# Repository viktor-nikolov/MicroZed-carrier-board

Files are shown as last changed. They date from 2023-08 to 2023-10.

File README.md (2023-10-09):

# MicroZed development carrier board



This repository provides KiCad design and production files for a [MicroZed](https://www.avnet.com/wps/portal/us/products/avnet-boards/avnet-board-families/microzed/) development carrier board (a.k.a. MicroZed carrier card).

### Please see [the repository's Wiki](https://github.com/viktor-nikolov/MicroZed-carrier-board/wiki) for details.

You are welcome to leave feedback in [the discussion](https://github.com/viktor-nikolov/MicroZed-carrier-board/discussions).

#### List of features:

- 106 digital I/O pins exposed via female headers
  
  - 16 I/O pins work on 5 V (exposed via two PMOD headers), and the rest of the pins work on 3.3 V

- 2 dedicated analog input pins XADC VP/VN

- 2 LEDs

- 2 push buttons

- 50 MHz precision oscillator (intended as an external clock input to the FPGA Programmable Logic)

- UART to USB conversion chip with the micro-USB connector (intended to enable UART communication for the FPGA Programmable Logic)

- Power input via micro-USB connector or screw terminal. On board power switch.

- Compatible with both [MicroZed 7010](https://www.avnet.com/shop/us/products/avnet-engineering-services/aes-z7mb-7z010-som-g-rev-h-3074457345644698173/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) and [MicroZed 7020](https://www.avnet.com/shop/us/products/avnet-engineering-services/aes-z7mb-7z020-som-g-rev-h-3074457345644698177/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).

&nbsp;

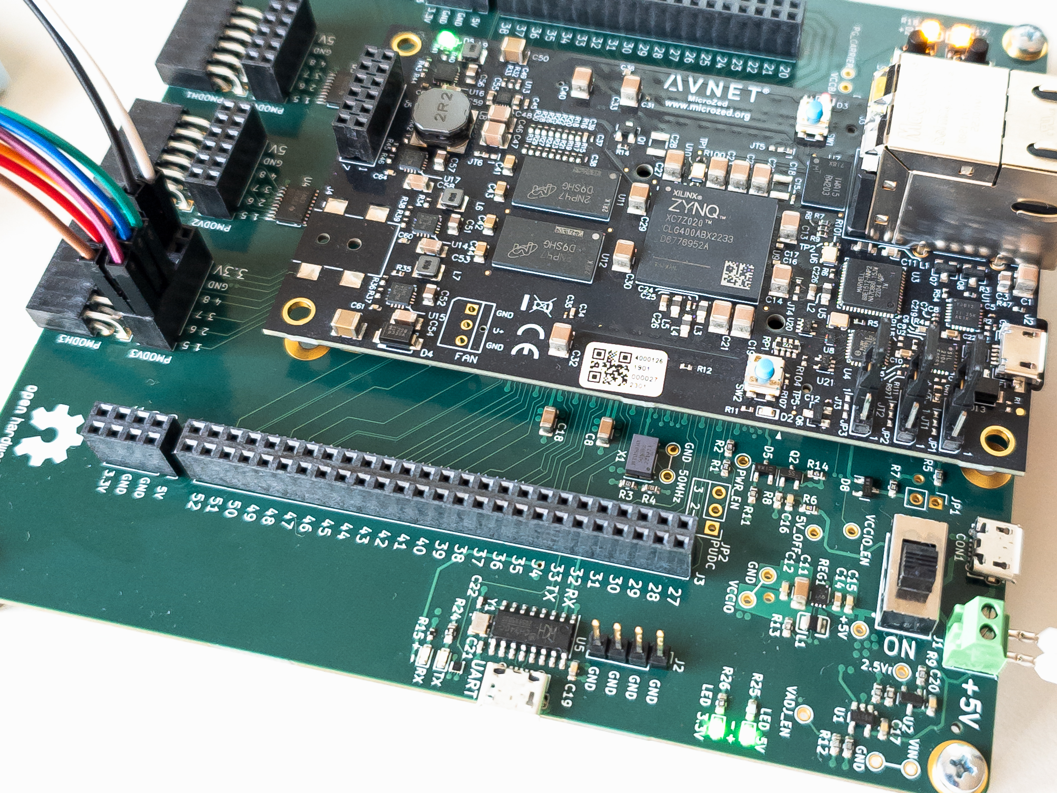
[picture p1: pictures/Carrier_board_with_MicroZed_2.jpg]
Carrier board with MicroZed
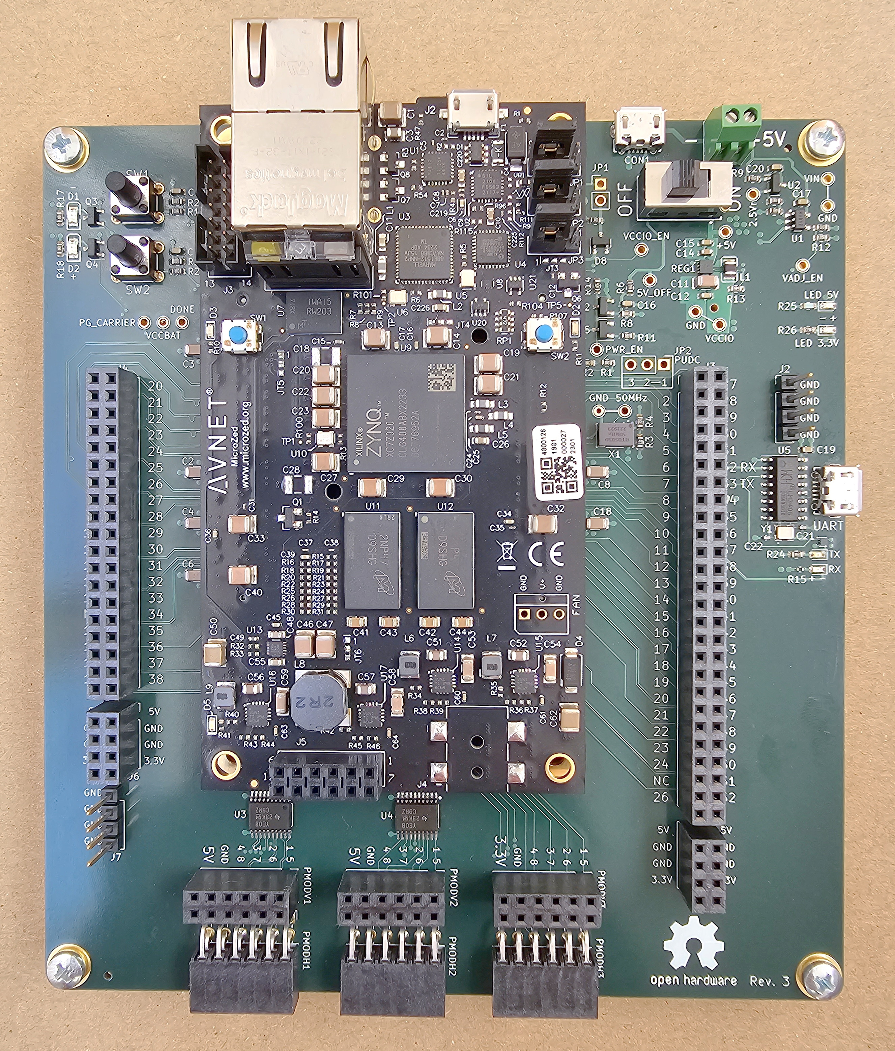
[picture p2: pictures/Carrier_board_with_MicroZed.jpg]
Carrier board with MicroZed
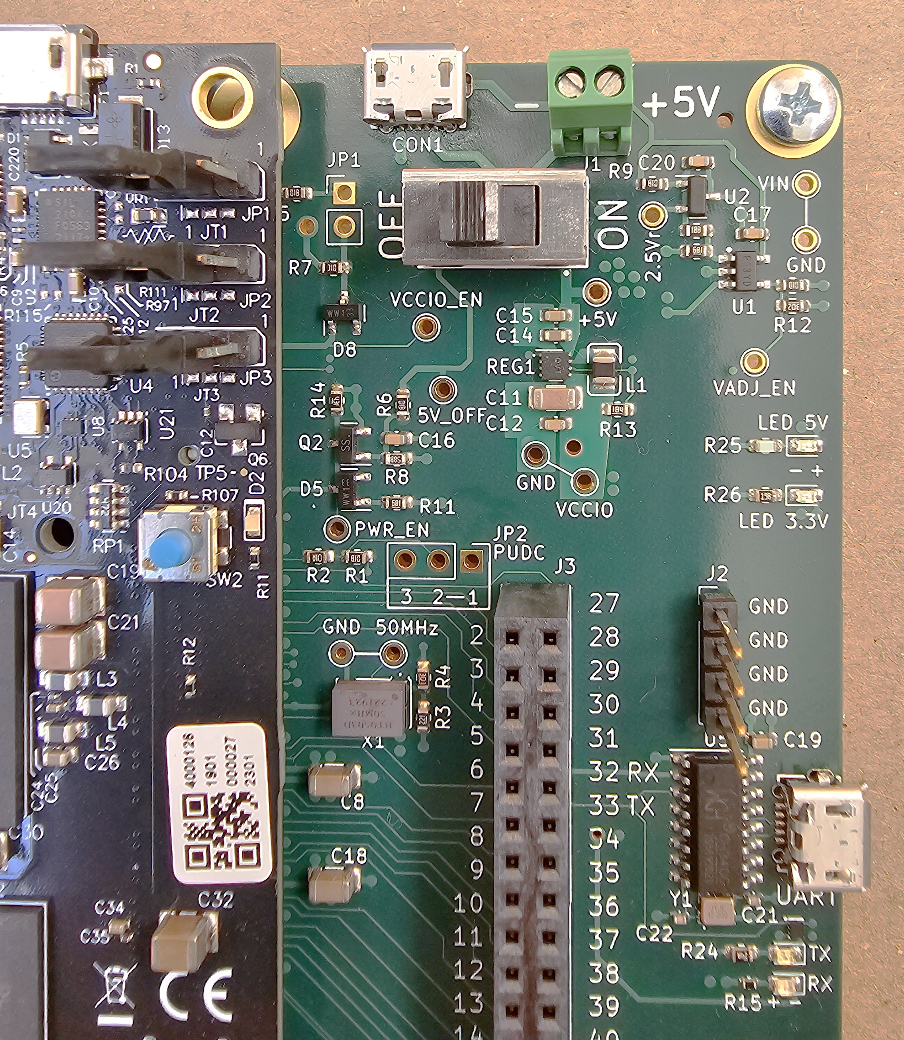
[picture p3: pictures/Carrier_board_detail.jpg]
Carrier board detail
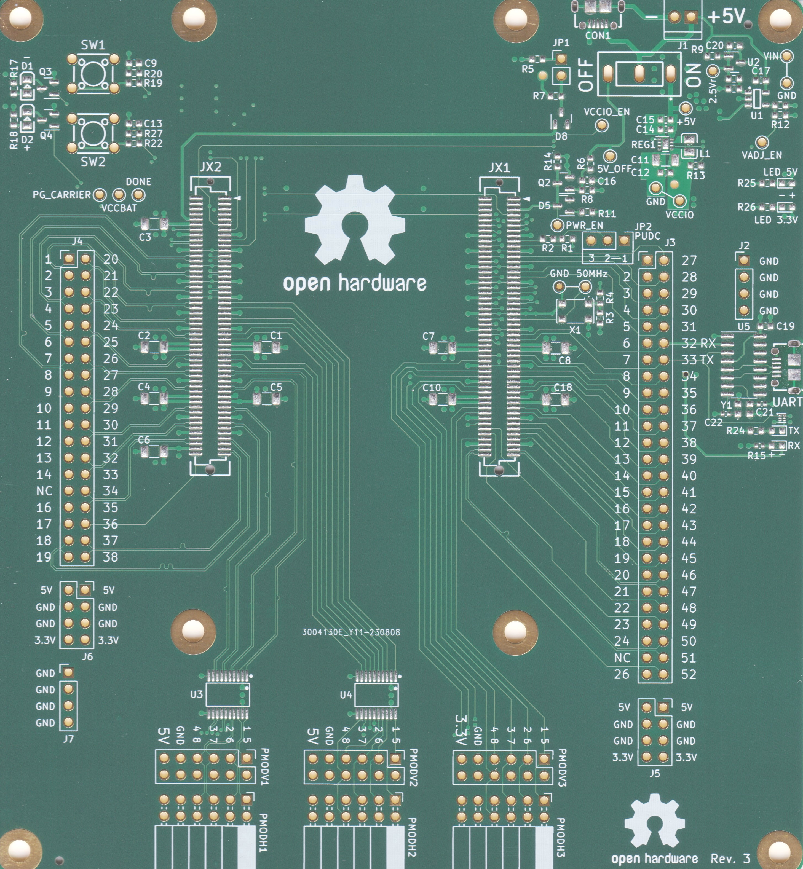
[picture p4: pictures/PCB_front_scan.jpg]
PCB front scan
            

See other photos [here](pictures).

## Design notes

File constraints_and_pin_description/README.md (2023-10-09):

### Please see [the repository's Wiki](https://github.com/viktor-nikolov/MicroZed-carrier-board/wiki#pinout) for details.

# Constraints files and pin description

- MicroZed carrier JX pinout tables &ndash; description of MicroZed JX1 and JX2 mezzanine connectors pins and their mapping to the J3, J4 and PMOD connectors on the carrier board.

- MicroZed_carrier_board_constraints_master.xdc – a general .xdc for the carrier board.
  
  - To use it in a Vivado project, uncomment the lines corresponding to used pins and, if needed, rename the used ports according to the top-level signal names in the project.

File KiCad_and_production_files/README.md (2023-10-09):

# KiCad design files and production files

### Please see [the repository's Wiki](https://github.com/viktor-nikolov/MicroZed-carrier-board/wiki/1.-Board-design) for details.

I designed the board in [KiCad 7.0](https://www.kicad.org/).

> [!IMPORTANT]
> 
> I designed the board from the very beginning with the intention to manufacture it using [JLCPCB Manufacturing and Assembly](https://jlcpcb.com/capabilities/pcb-assembly-capabilities). (I'm not affiliated with JLCPCB in any way. I'm just their customer. :smiley:). The production files in this repository are ready for ordering manufacturing and assembly from JLCPCB. 
> 
> The manufacture of this board is not exactly cheap. Production of the final revision of the board (2 assembled boards + 3 spare PCBs) cost me $194 + shipping costs. (However you can save $33 if you exclude the [50 MHz oscillator X1](https://jlcpcb.com/partdetail/Xtaltq-NT0503DH3I507BN50/C2920832) from the assembly.)
> 
> My selection of parts was dictated by the availability of suitable parts in the [JLCPCB Assembly Parts Library](http://jlcpcb.com/parts) as of August 2023.
> 
> Some parts are tiny and have pads on the bottom. You would need a reflow oven or a hot plate for DIY assembly.

See the [list of all parts](MicroZed_carrier_board_v4_parts.pdf) used in the design (also provided as [an Excel file](MicroZed_carrier_board_v4_parts.xlsx))

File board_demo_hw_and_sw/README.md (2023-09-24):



# Board demo HW & SW

### Please see [the repository's Wiki](https://github.com/viktor-nikolov/MicroZed-carrier-board/wiki/3.-HW-and-SW-demo-project) for details.

The demo was developed using Vivado 2023.1 and Vitis 2023.1.

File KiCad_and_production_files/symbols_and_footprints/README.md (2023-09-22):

# Custom symbols and footprints

I must create several custom symbols and footprints. I converted some footprints available online into KiCad. There are also footprints I copied from standard KiCad footprint library, but I had to change numbering of pads.

In KiCad you will see these symbols/footprints belonging to library "Viktor" (which is a library on my computer, not published on GitHub).

Before publishing the files on GitHub I exported all symbols and footprints used in the project into libraries placed in this folder. You can use symbols/footprints from these libraries in your project.

However I decided not to reassign symbols/footprints from library "Viktor" to the newly exported libraries in order to avoid creating errors in the PCB design.

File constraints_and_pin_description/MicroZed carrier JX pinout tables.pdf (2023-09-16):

JX1 Pin | MicroZed Net Name | Zynq | Name | VCCO Bank | Carrier board port name | Carrier board port impedance | Comment
1 | JTAG_TCK | F9 | TCK_0 | | (not connected)
2 | JTAG_TMS | J6 | TMS_0 | | (not connected)
3 | JTAG_TDO | F6 | TDO_0 | | (not connected)
4 | JTAG_TDI | G6 | TDI_0 | | (not connected)
5 | NetJX1_5 | | PWR_EN | | PWR_EN (TP5)
6 | NetJX1_6 | | CARRIER_SRST# | | (not connected)
7 | FPGA_VBATT | F11 | VCCBATT_0 | | VCCBAT (TP11)
8 | FPGA_DONE | R11 | DONE_0 | | DONE (TP12)
9 | JX1_SE_0 | R19 | IO_0_34 | 34 | J3_02 | single-ended 50Ω
10 | JX1_SE_1 | T19 | IO_25_34 | 34 | J3_01 | single-ended 50Ω
11 | JX1_LVDS_0_P | T11 | IO_L1P_T0_34 | 34 | J3_03 | single-ended 50Ω
12 | JX1_LVDS_1_P | T12 | IO_L2P_T0_34 | 34 | J3_05 | single-ended 50Ω
13 | JX1_LVDS_0_N | T10 | IO_L1N_T0_34 | 34 | J3_04 | single-ended 50Ω
14 | JX1_LVDS_1_N | U12 | IO_L2N_T0_34 | 34 | J3_06 | single-ended 50Ω
15 | GND | A8 | GND
16 | GND | A8 | GND
17 | JX1_LVDS_2_P | U13 | IO_L3P_T0_DQS_PUDC_B_34 | 34 | JP2 PUDC | (uncontrolled) | JP2 controlls PUDC
18 | JX1_LVDS_3_P | V12 | IO_L4P_T0_34 | 34 | J3_07 | single-ended 50Ω
19 | JX1_LVDS_2_N | V13 | IO_L3N_T0_DQS_34 | 34 | J3_27 | single-ended 50Ω
20 | JX1_LVDS_3_N | W13 | IO_L4N_T0_34 | 34 | J3_08 | single-ended 50Ω
21 | GND | A8 | GND
22 | GND | A8 | GND
23 | JX1_LVDS_4_P | T14 | IO_L5P_T0_34 | 34 | J3_28 | single-ended 50Ω
24 | JX1_LVDS_5_P | P14 | IO_L6P_T0_34 | 34 | J3_11 | single-ended 50Ω
25 | JX1_LVDS_4_N | T15 | IO_L5N_T0_34 | 34 | J3_29 | single-ended 50Ω
26 | JX1_LVDS_5_N | R14 | IO_L6N_T0_VREF_34 | 34 | J3_12 | single-ended 50Ω
27 | GND | A8 | GND
28 | GND | A8 | GND
29 | JX1_LVDS_6_P | Y16 | IO_L7P_T1_34 | 34 | J3_30 | single-ended 50Ω
30 | JX1_LVDS_7_P | W14 | IO_L8P_T1_34 | 34 | J3_13 | (uncontrolled)
31 | JX1_LVDS_6_N | Y17 | IO_L7N_T1_34 | 34 | J3_31 | single-ended 50Ω
32 | JX1_LVDS_7_N | Y14 | IO_L8N_T1_34 | 34 | J3_14 | (uncontrolled)
33 | GND | A8 | GND
34 | GND | A8 | GND
35 | JX1_LVDS_8_P | T16 | IO_L9P_T1_DQS_34 | 34 | J3_09 | single-ended 50Ω
36 | JX1_LVDS_9_P | V15 | IO_L10P_T1_34 | 34 | J3_17 | (uncontrolled)
37 | JX1_LVDS_8_N | U17 | IO_L9N_T1_DQS_34 | 34 | J3_10 | single-ended 50Ω
38 | JX1_LVDS_9_N | W15 | IO_L10N_T1_34 | 34 | J3_18 | (uncontrolled)
39 | GND | A8 | GND
40 | GND | A8 | GND
41 | JX1_LVDS_10_P | U14 | IO_L11P_T1_SRCC_34 | 34 | J3_15 | (uncontrolled)
42 | JX1_LVDS_11_P | U18 | IO_L12P_T1_MRCC_34 | 34 | J3_19 | (uncontrolled)
43 | JX1_LVDS_10_N | U15 | IO_L11N_T1_SRCC_34 | 34 | J3_16 | (uncontrolled)
44 | JX1_LVDS_11_N | U19 | IO_L12N_T1_MRCC_34 | 34 | J3_20 | (uncontrolled)
45 | GND | A8 | GND
46 | GND | A8 | GND
47 | JX1_LVDS_12_P | N18 | IO_L13P_T2_MRCC_34 | 34 | OSC_50MHZ | single-ended 50Ω | input from oscillator X1, 50 MHz ±0.5ppm
48 | JX1_LVDS_13_P | N20 | IO_L14P_T2_SRCC_34 | 34 | J3_21 | (uncontrolled)
49 | JX1_LVDS_12_N | P19 | IO_L13N_T2_MRCC_34 | 34 | (not connected)
50 | JX1_LVDS_13_N | P20 | IO_L14N_T2_SRCC_34 | 34 | J3_22 | (uncontrolled)
51 | GND | A8 | GND
52 | GND | A8 | GND
53 | JX1_LVDS_14_P | T20 | IO_L15P_T2_DQS_34 | 34 | J3_32_UART_RX | single-ended 50Ω | input from onboard USB to UART convert chip U5
54 | JX1_LVDS_15_P | V20 | IO_L16P_T2_34 | 34 | J3_23 | (uncontrolled)
55 | JX1_LVDS_14_N | U20 | IO_L15N_T2_DQS_34 | 34 | J3_33_UART_TX | single-ended 50Ω | output to onboard USB to UART convert chip U5
56 | JX1_LVDS_15_N | W20 | IO_L16N_T2_34 | 34 | J3_24 | (uncontrolled)
57 | VIN_HDR | | VIN
58 | VIN_HDR | | VIN
59 | VIN_HDR | | VIN
60 | VIN_HDR | | VIN
61 | JX1_LVDS_16_P | Y18 | IO_L17P_T2_34 | 34 | J3_34 | single-ended 50Ω
62 | JX1_LVDS_17_P | V16 | IO_L18P_T2_34 | 34 | PMOD3_8 | single-ended 50Ω
63 | JX1_LVDS_16_N | Y19 | IO_L17N_T2_34 | 34 | J3_35 | single-ended 50Ω
64 | JX1_LVDS_17_N | W16 | IO_L18N_T2_34 | 34 | PMOD3_7 | single-ended 50Ω
65 | GND | A8 | GND
66 | GND | A8 | GND
67 | JX1_LVDS_18_P | R16 | IO_L19P_T3_34 | 34 | J3_36 | single-ended 50Ω
68 | JX1_LVDS_19_P | T17 | IO_L20P_T3_34 | 34 | PMOD3_6 | single-ended 50Ω
69 | JX1_LVDS_18_N | R17 | IO_L19N_T3_VREF_34 | 34 | J3_37 | single-ended 50Ω
70 | JX1_LVDS_19_N | R18 | IO_L20N_T3_34 | 34 | PMOD3_5 | single-ended 50Ω
71 | GND | A8 | GND
72 | GND | A8 | GND
73 | JX1_LVDS_20_P | V17 | IO_L21P_T3_DQS_34 | 34 | J3_38 | single-ended 50Ω
74 | JX1_LVDS_21_P | W18 | IO_L22P_T3_34 | 34 | PMOD3_4 | single-ended 50Ω
75 | JX1_LVDS_20_N | V18 | IO_L21N_T3_DQS_34 | 34 | J3_39 | single-ended 50Ω
76 | JX1_LVDS_21_N | W19 | IO_L22N_T3_34 | 34 | PMOD3_3 | single-ended 50Ω
77 | GND | A8 | GND
78 | VCCO_34 | N19 | VCCIO | 34
79 | VCCO_34 | N19 | VCCIO | 34
80 | VCCO_34 | N19 | VCCIO | 34

Page 1 of 4

JX1 | | | | | Carrier board port name | Carrier board port impedance
81 | JX1_LVDS_22_P | N17 | IO_L23P_T3_34 | 34 | J3_40 | single-ended 50Ω
82 | JX1_LVDS_23_P | P15 | IO_L24P_T3_34 | 34 | PMOD3_2 | single-ended 50Ω
83 | JX1_LVDS_22_N | P18 | IO_L23N_T3_34 | 34 | J3_41 | single-ended 50Ω
84 | JX1_LVDS_23_N | P16 | IO_L24N_T3_34 | 34 | PMOD3_1 | single-ended 50Ω
85 | GND | A8 | GND
86 | GND | A8 | GND
87 | BANK13_LVDS_0_P | U7 | IO_L11P_T1_SRCC_13 | 13 | J3_42 | single-ended 50Ω | MicroZed 7020 only
88 | BANK13_LVDS_1_P | T9 | IO_L12P_T1_MRCC_13 | 13 | J3_26 | single-ended 50Ω | MicroZed 7020 only
89 | BANK13_LVDS_0_N | V7 | IO_L11N_T1_SRCC_13 | 13 | J3_43 | single-ended 50Ω | MicroZed 7020 only
90 | BANK13_LVDS_1_N | U10 | IO_L12N_T1_MRCC_13 | 13 | J3_48 | single-ended 50Ω | MicroZed 7020 only
91 | BANK13_LVDS_2_P | V8 | IO_L15P_T2_DQS_13 | 13 | J3_44 | single-ended 50Ω | MicroZed 7020 only
92 | BANK13_LVDS_3_P | T5 | IO_L19P_T3_13 | 13 | J3_49 | single-ended 50Ω | MicroZed 7020 only
93 | BANK13_LVDS_2_N | W8 | IO_L15N_T2_DQS_13 | 13 | J3_45 | single-ended 50Ω | MicroZed 7020 only
94 | BANK13_LVDS_3_N | U5 | IO_L19N_T3_VREF_13 | 13 | J3_52 | single-ended 50Ω | MicroZed 7020 only
95 | GND | A8 | GND
96 | GND | A8 | GND
97 | NetJX1_97 | K9 | XADC_VP | | J3_46 | diff. pair 100Ω | analog input
98 | NetJX1_98 | M9 | XADC_DXP | | J3_51 | diff. pair 100Ω | temperature-sensing diode pin (see UG475, Table1-12)
99 | NetJX1_99 | L10 | XADC_VN | | J3_47 | diff. pair 100Ω | analog input
100 | NetJX1_100 | M10 | XADC_DXN | | J3_50 | diff. pair 100Ω | temperature-sensing diode pin (see UG475, Table1-12)

Page 2 of 4

JX2 | | | | | Carrier board port name | Carrier board port impedance
1 | PMOD_D0 | E8 | PS_MIO13_500 | | (not connected)
2 | PMOD_D1 | E9 | PS_MIO10_500 | | (not connected)
3 | PMOD_D2 | C6 | PS_MIO11_500 | | (not connected)
4 | PMOD_D3 | D9 | PS_MIO12_500 | | (not connected)
5 | PMOD_D4 | E6 | PS_MIO0_500 | | (not connected)
6 | PMOD_D5 | B5 | PS_MIO9_500 | | (not connected)
7 | PMOD_D6 | C5 | PS_MIO14_500 | | (not connected)
8 | PMOD_D7 | C8 | PS_MIO15_500 | | (not connected)
9 | NetJX2_9 | R10 | INIT_B | | (not connected)
10 | NetJX2_10 | L6 | VCCIO_EN | | VCCIO_EN (TP7)
11 | PG_MODULE | C7 | PG_CARRIER | | PG_CARRIER (TP10)
12 | VIN_HDR | | VIN
13 | JX2_SE_0 | G14 | IO_0_35 | 35 | SWITCH2
14 | JX2_SE_1 | J15 | IO_25_35 | 35 | LED2
15 | GND | A8 | GND
16 | GND | A8 | GND
17 | JX2_LVDS_0_P | C20 | IO_L1P_T0_AD0P_35 | 35 | LED1
18 | JX2_LVDS_1_P | B19 | IO_L2P_T0_AD8P_35 | 35 | J4_10 | diff. pair 100Ω
19 | JX2_LVDS_0_N | B20 | IO_L1N_T0_AD0N_35 | 35 | SWITCH1
20 | JX2_LVDS_1_N | A20 | IO_L2N_T0_AD8N_35 | 35 | J4_09 | diff. pair 100Ω
21 | GND | A8 | GND
22 | GND | A8 | GND
23 | JX2_LVDS_2_P | E17 | IO_L3P_T0_DQS_AD1P_35 | 35 | J4_14 | diff. pair 100Ω
24 | JX2_LVDS_3_P | D19 | IO_L4P_T0_35 | 35 | J4_08 | diff. pair 100Ω
25 | JX2_LVDS_2_N | D18 | IO_L3N_T0_DQS_AD1N_35 | 35 | J4_13 | diff. pair 100Ω
26 | JX2_LVDS_3_N | D20 | IO_L4N_T0_35 | 35 | J4_07 | diff. pair 100Ω
27 | GND | A8 | GND
28 | GND | A8 | GND
29 | JX2_LVDS_4_P | E18 | IO_L5P_T0_AD9P_35 | 35 | J4_12 | diff. pair 100Ω
30 | JX2_LVDS_5_P | F16 | IO_L6P_T0_35 | 35 | J4_06 | diff. pair 100Ω
31 | JX2_LVDS_4_N | E19 | IO_L5N_T0_AD9N_35 | 35 | J4_11 | diff. pair 100Ω
32 | JX2_LVDS_5_N | F17 | IO_L6N_T0_VREF_35 | 35 | J4_05 | diff. pair 100Ω
33 | GND | A8 | GND
34 | GND | A8 | GND
35 | JX2_LVDS_6_P | L19 | IO_L9P_T1_DQS_AD3P_35 | 35 | J4_17 | diff. pair 100Ω
36 | JX2_LVDS_7_P | M19 | IO_L7P_T1_AD2P_35 | 35 | J4_04 | diff. pair 100Ω
37 | JX2_LVDS_6_N | L20 | IO_L9N_T1_DQS_AD3N_35 | 35 | J4_16 | diff. pair 100Ω
38 | JX2_LVDS_7_N | M20 | IO_L7N_T1_AD2N_35 | 35 | J4_03 | diff. pair 100Ω
39 | GND | A8 | GND
40 | GND | A8 | GND
41 | JX2_LVDS_8_P | M17 | IO_L8P_T1_AD10P_35 | 35 | PMOD2_1 | single-ended 50Ω | Output shifted to 5V
42 | JX2_LVDS_9_P | K19 | IO_L10P_T1_AD11P_35 | 35 | J4_02 | diff. pair 100Ω
43 | JX2_LVDS_8_N | M18 | IO_L8N_T1_AD10N_35 | 35 | PMOD2_2 | single-ended 50Ω | Output shifted to 5V
44 | JX2_LVDS_9_N | J19 | IO_L10N_T1_AD11N_35 | 35 | J4_01 | diff. pair 100Ω
45 | GND | A8 | GND
46 | GND | A8 | GND
47 | JX2_LVDS_10_P | L16 | IO_L11P_T1_SRCC_35 | 35 | PMOD2_3 | single-ended 50Ω | Output shifted to 5V
48 | JX2_LVDS_11_P | K17 | IO_L12P_T1_MRCC_35 | 35 | J4_20 | diff. pair 100Ω
49 | JX2_LVDS_10_N | L17 | IO_L11N_T1_SRCC_35 | 35 | PMOD2_4 | single-ended 50Ω | Output shifted to 5V
50 | JX2_LVDS_11_N | K18 | IO_L12N_T1_MRCC_35 | 35 | J4_21 | diff. pair 100Ω
51 | GND | A8 | GND
52 | GND | A8 | GND
53 | JX2_LVDS_12_P | H16 | IO_L13P_T2_MRCC_35 | 35 | PMOD2_5 | single-ended 50Ω | Output shifted to 5V
54 | JX2_LVDS_13_P | J18 | IO_L14P_T2_AD4P_SRCC_35 | 35 | J4_22 | diff. pair 100Ω
55 | JX2_LVDS_12_N | H17 | IO_L13N_T2_MRCC_35 | 35 | PMOD2_6 | single-ended 50Ω | Output shifted to 5V
56 | JX2_LVDS_13_N | H18 | IO_L14N_T2_AD4N_SRCC_35 | 35 | J4_23 | diff. pair 100Ω
57 | VIN_HDR | | VIN
58 | VIN_HDR | | VIN
59 | VIN_HDR | | VIN
60 | VIN_HDR | | VIN
61 | JX2_LVDS_14_P | G17 | IO_L16P_T2_35 | 35 | PMOD2_7 | single-ended 50Ω | Output shifted to 5V
62 | JX2_LVDS_15_P | F19 | IO_L15P_T2_DQS_AD12P_35 | 35 | J4_24 | diff. pair 100Ω
63 | JX2_LVDS_14_N | G18 | IO_L16N_T2_35 | 35 | PMOD2_8 | single-ended 50Ω | Output shifted to 5V
64 | JX2_LVDS_15_N | F20 | IO_L15N_T2_DQS_AD12N_35 | 35 | J4_25 | diff. pair 100Ω
65 | GND | A8 | GND
66 | GND | A8 | GND
67 | JX2_LVDS_16_P | G19 | IO_L18P_T2_AD13P_35 | 35 | PMOD1_1 | diff. pair 100Ω | Output shifted to 5V
68 | JX2_LVDS_17_P | J20 | IO_L17P_T2_AD5P_35 | 35 | J4_26 | diff. pair 100Ω
69 | JX2_LVDS_16_N | G20 | IO_L18N_T2_AD13N_35 | 35 | PMOD1_2 | diff. pair 100Ω | Output shifted to 5V
70 | JX2_LVDS_17_N | H20 | IO_L17N_T2_AD5N_35 | 35 | J4_27 | diff. pair 100Ω
71 | GND | A8 | GND
72 | GND | A8 | GND

JX2 | | | | | Carrier board port name | Carrier board port impedance
73 | JX2_LVDS_18_P | K14 | IO_L20P_T3_AD6P_35 | 35 | PMOD1_3 | diff. pair 100Ω | Output shifted to 5V
74 | JX2_LVDS_19_P | H15 | IO_L19P_T3_35 | 35 | J4_28 | diff. pair 100Ω
75 | JX2_LVDS_18_N | J14 | IO_L20N_T3_AD6N_35 | 35 | PMOD1_4 | diff. pair 100Ω | Output shifted to 5V
76 | JX2_LVDS_19_N | G15 | IO_L19N_T3_VREF_35 | 35 | J4_29 | diff. pair 100Ω
77 | GND | A8 | GND
78 | VCCO_35 | C19 | VCCIO | 35
79 | VCCO_35 | C19 | VCCIO | 35
80 | VCCO_35 | C19 | VCCIO | 35
81 | JX2_LVDS_20_P | N15 | IO_L21P_T3_DQS_AD14P_35 | 35 | PMOD1_5 | diff. pair 100Ω | Output shifted to 5V
82 | JX2_LVDS_21_P | L14 | IO_L22P_T3_AD7P_35 | 35 | J4_30 | diff. pair 100Ω
83 | JX2_LVDS_20_N | N16 | IO_L21N_T3_DQS_AD14N_35 | 35 | PMOD1_6 | diff. pair 100Ω | Output shifted to 5V
84 | JX2_LVDS_21_N | L15 | IO_L22N_T3_AD7N_35 | 35 | J4_31 | diff. pair 100Ω
85 | GND | A8 | GND
86 | GND | A8 | GND
87 | JX2_LVDS_22_P | M14 | IO_L23P_T3_35 | 35 | PMOD1_7 | diff. pair 100Ω | Output shifted to 5V
88 | JX2_LVDS_23_P | K16 | IO_L24P_T3_AD15P_35 | 35 | J4_32 | diff. pair 100Ω
89 | JX2_LVDS_22_N | M15 | IO_L23N_T3_35 | 35 | PMOD1_8 | diff. pair 100Ω | Output shifted to 5V
90 | JX2_LVDS_23_N | J16 | IO_L24N_T3_AD15N_35 | 35 | J4_33 | diff. pair 100Ω
91 | GND | A8 | GND
92 | GND | A8 | GND
93 | BANK13_LVDS_4_P | Y12 | IO_L20P_T3_13 | 13 | J4_18 | diff. pair 100Ω | MicroZed 7020 only
94 | BANK13_LVDS_5_P | V11 | IO_L21P_T3_DQS_13 | 13 | J4_34 | diff. pair 100Ω | MicroZed 7020 only
95 | BANK13_LVDS_4_N | Y13 | IO_L20N_T3_13 | 13 | J4_19 | diff. pair 100Ω | MicroZed 7020 only
96 | BANK13_LVDS_5_N | V10 | IO_L21N_T3_DQS_13 | 13 | J4_35 | diff. pair 100Ω | MicroZed 7020 only
97 | BANK13_LVDS_6_P | V6 | IO_L22P_T3_13 | 13 | J4_38 | diff. pair 100Ω | MicroZed 7020 only
98 | VCCO_13 | T8 | VCCIO | 13 | | | MicroZed 7020 only
99 | BANK13_LVDS_6_N | W6 | IO_L22N_T3_13 | 13 | J4_37 | diff. pair 100Ω | MicroZed 7020 only
100 | BANK13_SE_0 | V5 | IO_L6N_T0_VREF_13 | 13 | J4_36 | single-ended 50Ω | MicroZed 7020 only

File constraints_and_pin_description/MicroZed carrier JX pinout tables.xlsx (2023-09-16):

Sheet: JX1
JX1 Pin | MicroZed Net Name | Zynq Pin | Zynq Name | VCCO Bank | Carrier board port name | Carrier board port impedance | Comment | Constraint
1 | JTAG_TCK | F9 | TCK_0 |  | (not connected)
2 | JTAG_TMS | J6 | TMS_0 |  | (not connected)
3 | JTAG_TDO | F6 | TDO_0 |  | (not connected)
4 | JTAG_TDI | G6 | TDI_0 |  | (not connected)
5 | NetJX1_5 |  | PWR_EN |  | PWR_EN (TP5)
6 | NetJX1_6 |  | CARRIER_SRST# |  | (not connected)
7 | FPGA_VBATT | F11 | VCCBATT_0 |  | VCCBAT (TP11)
8 | FPGA_DONE | R11 | DONE_0 |  | DONE (TP12)
9 | JX1_SE_0 | R19 | IO_0_34 | 34 | J3_02 | single-ended 50Ω |  | set_property -dict { PACKAGE_PIN R19 IOSTANDARD LVCMOS33 } [get_ports { J3_02 }];
10 | JX1_SE_1 | T19 | IO_25_34 | 34 | J3_01 | single-ended 50Ω |  | set_property -dict { PACKAGE_PIN T19 IOSTANDARD LVCMOS33 } [get_ports { J3_01 }];
11 | JX1_LVDS_0_P | T11 | IO_L1P_T0_34 | 34 | J3_03 | single-ended 50Ω |  | set_property -dict { PACKAGE_PIN T11 IOSTANDARD LVCMOS33 } [get_ports { J3_03 }];
12 | JX1_LVDS_1_P | T12 | IO_L2P_T0_34 | 34 | J3_05 | single-ended 50Ω |  | set_property -dict { PACKAGE_PIN T12 IOSTANDARD LVCMOS33 } [get_ports { J3_05 }];
13 | JX1_LVDS_0_N | T10 | IO_L1N_T0_34 | 34 | J3_04 | single-ended 50Ω |  | set_property -dict { PACKAGE_PIN T10 IOSTANDARD LVCMOS33 } [get_ports { J3_04 }];
14 | JX1_LVDS_1_N | U12 | IO_L2N_T0_34 | 34 | J3_06 | single-ended 50Ω |  | set_property -dict { PACKAGE_PIN U12 IOSTANDARD LVCMOS33 } [get_ports { J3_06 }];
15 | GND | A8 | GND
16 | GND | A8 | GND
17 | JX1_LVDS_2_P | U13 | IO_L3P_T0_DQS_PUDC_B_34 | 34 | JP2 PUDC | (uncontrolled) | JP2 controlls PUDC
18 | JX1_LVDS_3_P | V12 | IO_L4P_T0_34 | 34 | J3_07 | single-ended 50Ω |  | set_property -dict { PACKAGE_PIN V12 IOSTANDARD LVCMOS33 } [get_ports { J3_07 }];
19 | JX1_LVDS_2_N | V13 | IO_L3N_T0_DQS_34 | 34 | J3_27 | single-ended 50Ω |  | set_property -dict { PACKAGE_PIN V13 IOSTANDARD LVCMOS33 } [get_ports { J3_27 }];
20 | JX1_LVDS_3_N | W13 | IO_L4N_T0_34 | 34 | J3_08 | single-ended 50Ω |  | set_property -dict { PACKAGE_PIN W13 IOSTANDARD LVCMOS33 } [get_ports { J3_08 }];
21 | GND | A8 | GND
22 | GND | A8 | GND
23 | JX1_LVDS_4_P | T14 | IO_L5P_T0_34 | 34 | J3_28 | single-ended 50Ω |  | set_property -dict { PACKAGE_PIN T14 IOSTANDARD LVCMOS33 } [get_ports { J3_28 }];
24 | JX1_LVDS_5_P | P14 | IO_L6P_T0_34 | 34 | J3_11 | single-ended 50Ω |  | set_property -dict { PACKAGE_PIN P14 IOSTANDARD LVCMOS33 } [get_ports { J3_11 }];
25 | JX1_LVDS_4_N | T15 | IO_L5N_T0_34 | 34 | J3_29 | single-ended 50Ω |  | set_property -dict { PACKAGE_PIN T15 IOSTANDARD LVCMOS33 } [get_ports { J3_29 }];
26 | JX1_LVDS_5_N | R14 | IO_L6N_T0_VREF_34 | 34 | J3_12 | single-ended 50Ω |  | set_property -dict { PACKAGE_PIN R14 IOSTANDARD LVCMOS33 } [get_ports { J3_12 }];
27 | GND | A8 | GND
28 | GND | A8 | GND
29 | JX1_LVDS_6_P | Y16 | IO_L7P_T1_34 | 34 | J3_30 | single-ended 50Ω |  | set_property -dict { PACKAGE_PIN Y16 IOSTANDARD LVCMOS33 } [get_ports { J3_30 }];
30 | JX1_LVDS_7_P | W14 | IO_L8P_T1_34 | 34 | J3_13 | (uncontrolled) |  | set_property -dict { PACKAGE_PIN W14 IOSTANDARD LVCMOS33 } [get_ports { J3_13 }];
31 | JX1_LVDS_6_N | Y17 | IO_L7N_T1_34 | 34 | J3_31 | single-ended 50Ω |  | set_property -dict { PACKAGE_PIN Y17 IOSTANDARD LVCMOS33 } [get_ports { J3_31 }];
32 | JX1_LVDS_7_N | Y14 | IO_L8N_T1_34 | 34 | J3_14 | (uncontrolled) |  | set_property -dict { PACKAGE_PIN Y14 IOSTANDARD LVCMOS33 } [get_ports { J3_14 }];
33 | GND | A8 | GND
34 | GND | A8 | GND
35 | JX1_LVDS_8_P | T16 | IO_L9P_T1_DQS_34 | 34 | J3_09 | single-ended 50Ω |  | set_property -dict { PACKAGE_PIN T16 IOSTANDARD LVCMOS33 } [get_ports { J3_09 }];
36 | JX1_LVDS_9_P | V15 | IO_L10P_T1_34 | 34 | J3_17 | (uncontrolled) |  | set_property -dict { PACKAGE_PIN V15 IOSTANDARD LVCMOS33 } [get_ports { J3_17 }];
37 | JX1_LVDS_8_N | U17 | IO_L9N_T1_DQS_34 | 34 | J3_10 | single-ended 50Ω |  | set_property -dict { PACKAGE_PIN U17 IOSTANDARD LVCMOS33 } [get_ports { J3_10 }];
38 | JX1_LVDS_9_N | W15 | IO_L10N_T1_34 | 34 | J3_18 | (uncontrolled) |  | set_property -dict { PACKAGE_PIN W15 IOSTANDARD LVCMOS33 } [get_ports { J3_18 }];
39 | GND | A8 | GND
40 | GND | A8 | GND
41 | JX1_LVDS_10_P | U14 | IO_L11P_T1_SRCC_34 | 34 | J3_15 | (uncontrolled) |  | set_property -dict { PACKAGE_PIN U14 IOSTANDARD LVCMOS33 } [get_ports { J3_15 }];
42 | JX1_LVDS_11_P | U18 | IO_L12P_T1_MRCC_34 | 34 | J3_19 | (uncontrolled) |  | set_property -dict { PACKAGE_PIN U18 IOSTANDARD LVCMOS33 } [get_ports { J3_19 }];
43 | JX1_LVDS_10_N | U15 | IO_L11N_T1_SRCC_34 | 34 | J3_16 | (uncontrolled) |  | set_property -dict { PACKAGE_PIN U15 IOSTANDARD LVCMOS33 } [get_ports { J3_16 }];
44 | JX1_LVDS_11_N | U19 | IO_L12N_T1_MRCC_34 | 34 | J3_20 | (uncontrolled) |  | set_property -dict { PACKAGE_PIN U19 IOSTANDARD LVCMOS33 } [get_ports { J3_20 }];
45 | GND | A8 | GND
46 | GND | A8 | GND
47 | JX1_LVDS_12_P | N18 | IO_L13P_T2_MRCC_34 | 34 | OSC_50MHZ | single-ended 50Ω | input from oscillator X1, 50 MHz ±0.5ppm | set_property -dict { PACKAGE_PIN N18 IOSTANDARD LVCMOS33 } [get_ports { OSC_50MHZ }];
48 | JX1_LVDS_13_P | N20 | IO_L14P_T2_SRCC_34 | 34 | J3_21 | (uncontrolled) |  | set_property -dict { PACKAGE_PIN N20 IOSTANDARD LVCMOS33 } [get_ports { J3_21 }];
49 | JX1_LVDS_12_N | P19 | IO_L13N_T2_MRCC_34 | 34 | (not connected)
50 | JX1_LVDS_13_N | P20 | IO_L14N_T2_SRCC_34 | 34 | J3_22 | (uncontrolled) |  | set_property -dict { PACKAGE_PIN P20 IOSTANDARD LVCMOS33 } [get_ports { J3_22 }];
51 | GND | A8 | GND
52 | GND | A8 | GND
53 | JX1_LVDS_14_P | T20 | IO_L15P_T2_DQS_34 | 34 | J3_32_UART_RX | single-ended 50Ω | input from onboard USB to UART convert chip U5 | set_property -dict { PACKAGE_PIN T20 IOSTANDARD LVCMOS33 } [get_ports { J3_32_UART_RX }];
54 | JX1_LVDS_15_P | V20 | IO_L16P_T2_34 | 34 | J3_23 | (uncontrolled) |  | set_property -dict { PACKAGE_PIN V20 IOSTANDARD LVCMOS33 } [get_ports { J3_23 }];
55 | JX1_LVDS_14_N | U20 | IO_L15N_T2_DQS_34 | 34 | J3_33_UART_TX | single-ended 50Ω | output to onboard USB to UART convert chip U5 | set_property -dict { PACKAGE_PIN U20 IOSTANDARD LVCMOS33 } [get_ports { J3_33_UART_TX }];
56 | JX1_LVDS_15_N | W20 | IO_L16N_T2_34 | 34 | J3_24 | (uncontrolled) |  | set_property -dict { PACKAGE_PIN W20 IOSTANDARD LVCMOS33 } [get_ports { J3_24 }];
57 | VIN_HDR |  | VIN
58 | VIN_HDR |  | VIN
59 | VIN_HDR |  | VIN
60 | VIN_HDR |  | VIN
61 | JX1_LVDS_16_P | Y18 | IO_L17P_T2_34 | 34 | J3_34 | single-ended 50Ω |  | set_property -dict { PACKAGE_PIN Y18 IOSTANDARD LVCMOS33 } [get_ports { J3_34 }];
62 | JX1_LVDS_17_P | V16 | IO_L18P_T2_34 | 34 | PMOD3_8 | single-ended 50Ω |  | set_property -dict { PACKAGE_PIN V16 IOSTANDARD LVCMOS33 } [get_ports { PMOD3_8 }];
63 | JX1_LVDS_16_N | Y19 | IO_L17N_T2_34 | 34 | J3_35 | single-ended 50Ω |  | set_property -dict { PACKAGE_PIN Y19 IOSTANDARD LVCMOS33 } [get_ports { J3_35 }];
64 | JX1_LVDS_17_N | W16 | IO_L18N_T2_34 | 34 | PMOD3_7 | single-ended 50Ω |  | set_property -dict { PACKAGE_PIN W16 IOSTANDARD LVCMOS33 } [get_ports { PMOD3_7 }];
65 | GND | A8 | GND
66 | GND | A8 | GND
67 | JX1_LVDS_18_P | R16 | IO_L19P_T3_34 | 34 | J3_36 | single-ended 50Ω |  | set_property -dict { PACKAGE_PIN R16 IOSTANDARD LVCMOS33 } [get_ports { J3_36 }];
68 | JX1_LVDS_19_P | T17 | IO_L20P_T3_34 | 34 | PMOD3_6 | single-ended 50Ω |  | set_property -dict { PACKAGE_PIN T17 IOSTANDARD LVCMOS33 } [get_ports { PMOD3_6 }];
69 | JX1_LVDS_18_N | R17 | IO_L19N_T3_VREF_34 | 34 | J3_37 | single-ended 50Ω |  | set_property -dict { PACKAGE_PIN R17 IOSTANDARD LVCMOS33 } [get_ports { J3_37 }];
70 | JX1_LVDS_19_N | R18 | IO_L20N_T3_34 | 34 | PMOD3_5 | single-ended 50Ω |  | set_property -dict { PACKAGE_PIN R18 IOSTANDARD LVCMOS33 } [get_ports { PMOD3_5 }];
71 | GND | A8 | GND
72 | GND | A8 | GND
73 | JX1_LVDS_20_P | V17 | IO_L21P_T3_DQS_34 | 34 | J3_38 | single-ended 50Ω |  | set_property -dict { PACKAGE_PIN V17 IOSTANDARD LVCMOS33 } [get_ports { J3_38 }];
74 | JX1_LVDS_21_P | W18 | IO_L22P_T3_34 | 34 | PMOD3_4 | single-ended 50Ω |  | set_property -dict { PACKAGE_PIN W18 IOSTANDARD LVCMOS33 } [get_ports { PMOD3_4 }];
75 | JX1_LVDS_20_N | V18 | IO_L21N_T3_DQS_34 | 34 | J3_39 | single-ended 50Ω |  | set_property -dict { PACKAGE_PIN V18 IOSTANDARD LVCMOS33 } [get_ports { J3_39 }];
76 | JX1_LVDS_21_N | W19 | IO_L22N_T3_34 | 34 | PMOD3_3 | single-ended 50Ω |  | set_property -dict { PACKAGE_PIN W19 IOSTANDARD LVCMOS33 } [get_ports { PMOD3_3 }];
77 | GND | A8 | GND
78 | VCCO_34 | N19 | VCCIO | 34
79 | VCCO_34 | N19 | VCCIO | 34
80 | VCCO_34 | N19 | VCCIO | 34
81 | JX1_LVDS_22_P | N17 | IO_L23P_T3_34 | 34 | J3_40 | single-ended 50Ω |  | set_property -dict { PACKAGE_PIN N17 IOSTANDARD LVCMOS33 } [get_ports { J3_40 }];
82 | JX1_LVDS_23_P | P15 | IO_L24P_T3_34 | 34 | PMOD3_2 | single-ended 50Ω |  | set_property -dict { PACKAGE_PIN P15 IOSTANDARD LVCMOS33 } [get_ports { PMOD3_2 }];
83 | JX1_LVDS_22_N | P18 | IO_L23N_T3_34 | 34 | J3_41 | single-ended 50Ω |  | set_property -dict { PACKAGE_PIN P18 IOSTANDARD LVCMOS33 } [get_ports { J3_41 }];
84 | JX1_LVDS_23_N | P16 | IO_L24N_T3_34 | 34 | PMOD3_1 | single-ended 50Ω |  | set_property -dict { PACKAGE_PIN P16 IOSTANDARD LVCMOS33 } [get_ports { PMOD3_1 }];
85 | GND | A8 | GND
86 | GND | A8 | GND
87 | BANK13_LVDS_0_P | U7 | IO_L11P_T1_SRCC_13 | 13 | J3_42 | single-ended 50Ω | MicroZed 7020 only | set_property -dict { PACKAGE_PIN U7 IOSTANDARD LVCMOS33 } [get_ports { J3_42 }];
88 | BANK13_LVDS_1_P | T9 | IO_L12P_T1_MRCC_13 | 13 | J3_26 | single-ended 50Ω | MicroZed 7020 only | set_property -dict { PACKAGE_PIN T9 IOSTANDARD LVCMOS33 } [get_ports { J3_26 }];
89 | BANK13_LVDS_0_N | V7 | IO_L11N_T1_SRCC_13 | 13 | J3_43 | single-ended 50Ω | MicroZed 7020 only | set_property -dict { PACKAGE_PIN V7 IOSTANDARD LVCMOS33 } [get_ports { J3_43 }];
90 | BANK13_LVDS_1_N | U10 | IO_L12N_T1_MRCC_13 | 13 | J3_48 | single-ended 50Ω | MicroZed 7020 only | set_property -dict { PACKAGE_PIN U10 IOSTANDARD LVCMOS33 } [get_ports { J3_48 }];
91 | BANK13_LVDS_2_P | V8 | IO_L15P_T2_DQS_13 | 13 | J3_44 | single-ended 50Ω | MicroZed 7020 only | set_property -dict { PACKAGE_PIN V8 IOSTANDARD LVCMOS33 } [get_ports { J3_44 }];
92 | BANK13_LVDS_3_P | T5 | IO_L19P_T3_13 | 13 | J3_49 | single-ended 50Ω | MicroZed 7020 only | set_property -dict { PACKAGE_PIN T5 IOSTANDARD LVCMOS33 } [get_ports { J3_49 }];
93 | BANK13_LVDS_2_N | W8 | IO_L15N_T2_DQS_13 | 13 | J3_45 | single-ended 50Ω | MicroZed 7020 only | set_property -dict { PACKAGE_PIN W8 IOSTANDARD LVCMOS33 } [get_ports { J3_45 }];
94 | BANK13_LVDS_3_N | U5 | IO_L19N_T3_VREF_13 | 13 | J3_52 | single-ended 50Ω | MicroZed 7020 only | set_property -dict { PACKAGE_PIN U5 IOSTANDARD LVCMOS33 } [get_ports { J3_52 }];
95 | GND | A8 | GND
96 | GND | A8 | GND
97 | NetJX1_97 | K9 | XADC_VP |  | J3_46 | diff. pair 100Ω | analog input | set_property PACKAGE_PIN K9 [get_ports { J3_46 }];
98 | NetJX1_98 | M9 | XADC_DXP |  | J3_51 | diff. pair 100Ω | temperature-sensing diode pin (see UG475, Table1-12)
99 | NetJX1_99 | L10 | XADC_VN |  | J3_47 | diff. pair 100Ω | analog input | set_property PACKAGE_PIN L10 [get_ports { J3_47 }];
100 | NetJX1_100 | M10 | XADC_DXN |  | J3_50 | diff. pair 100Ω | temperature-sensing diode pin (see UG475, Table1-12)
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

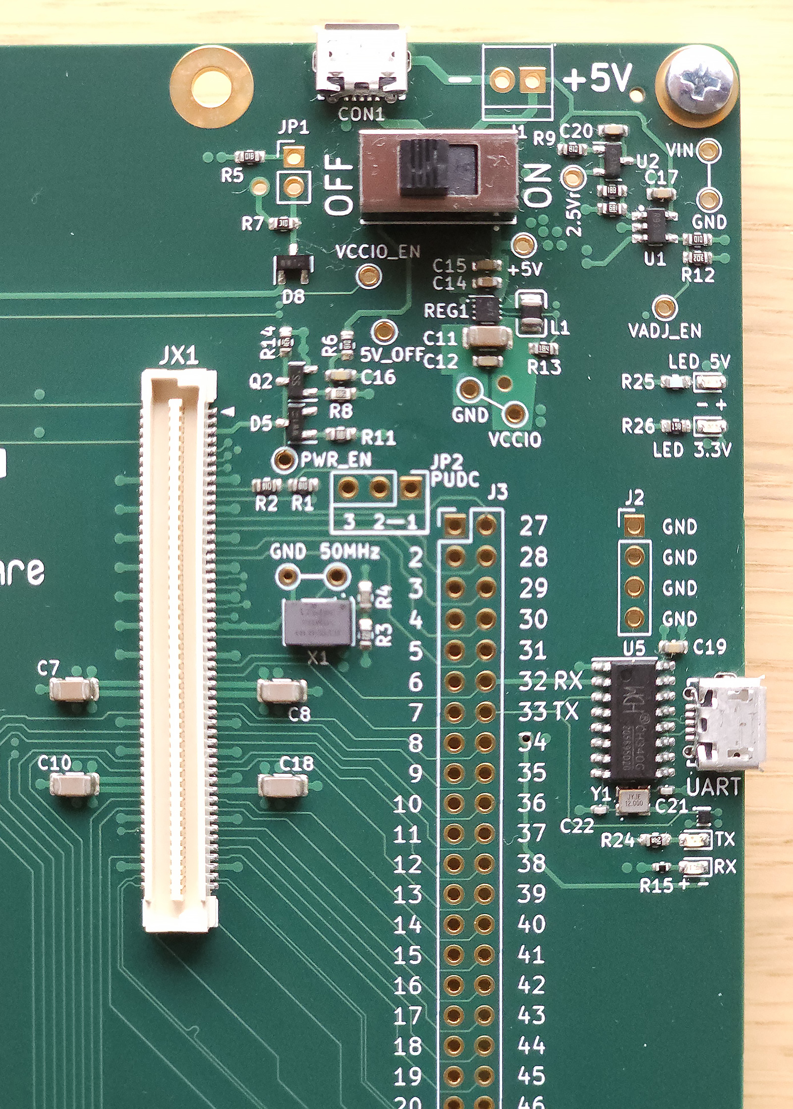
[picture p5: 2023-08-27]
pictures/Carrier_board_detail_without_connectors.jpg

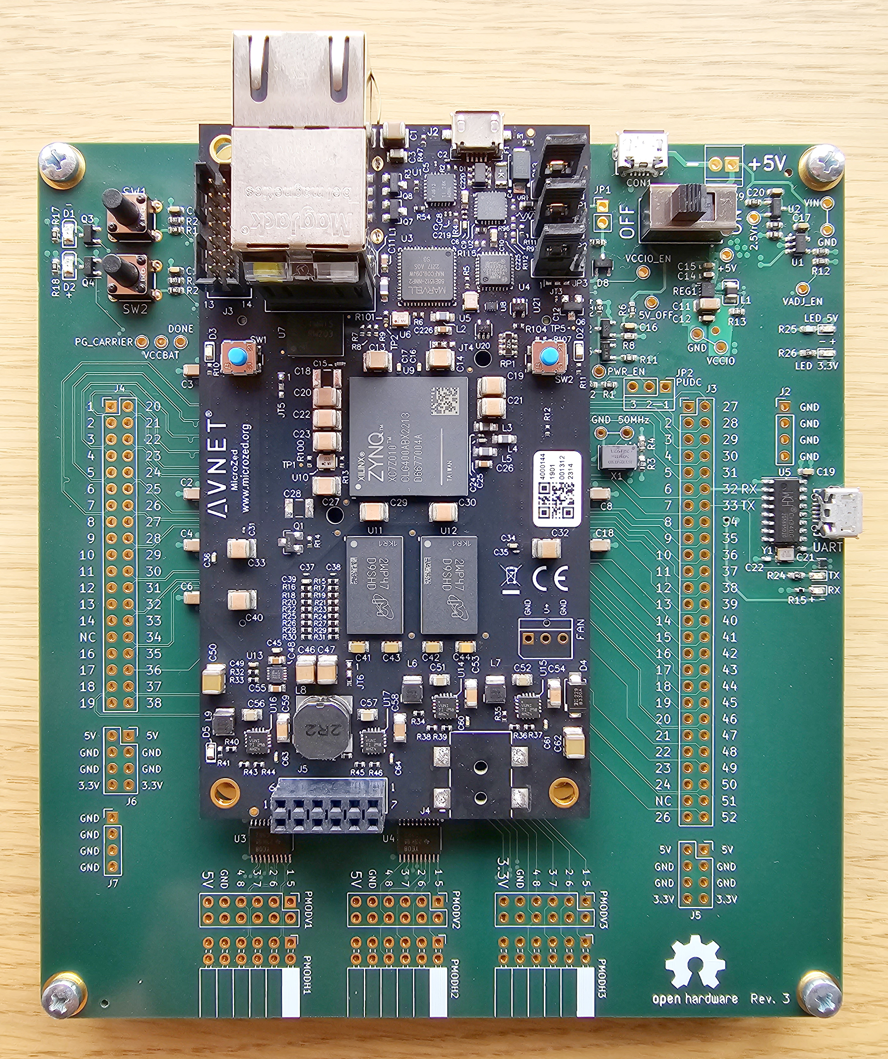
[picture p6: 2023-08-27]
pictures/Carrier_board_with_MicroZed_without_connectors.jpg

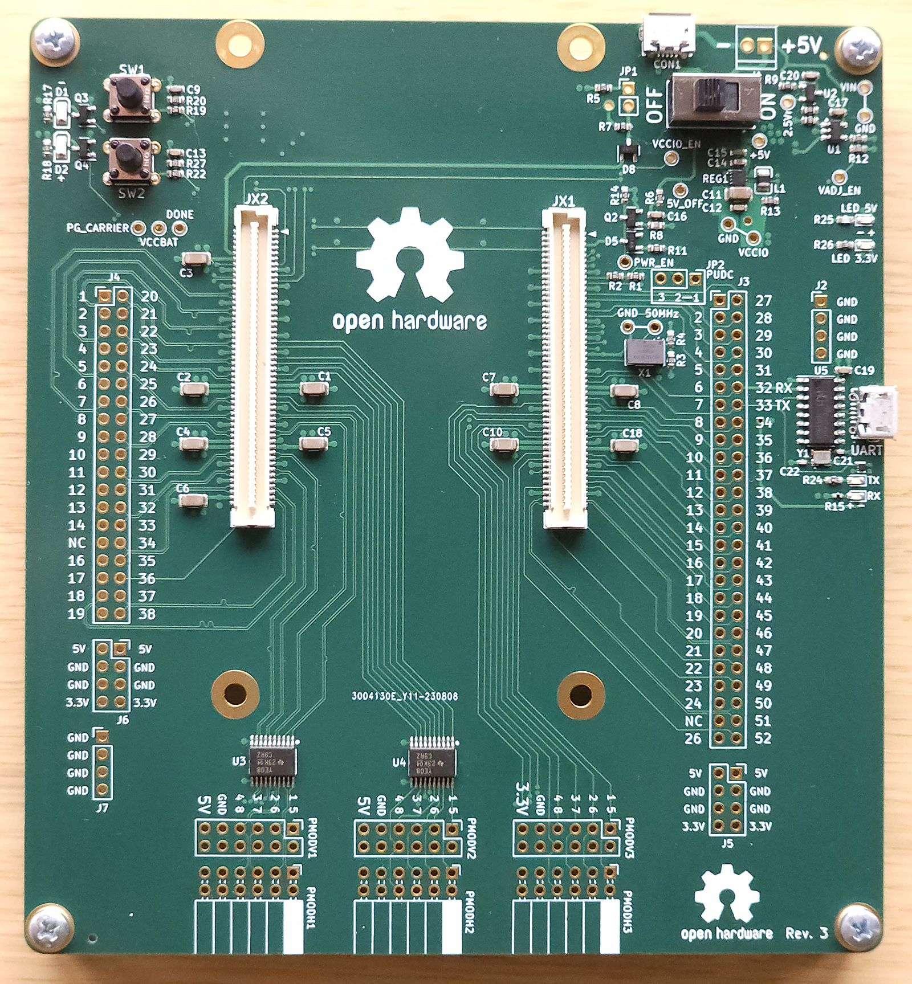
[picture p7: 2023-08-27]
pictures/Carrier_board_without_connectors.jpg

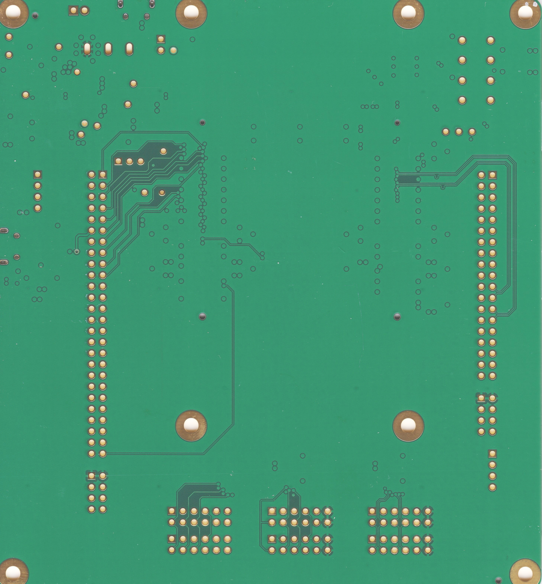
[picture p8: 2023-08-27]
pictures/PCB_back_scan.jpg

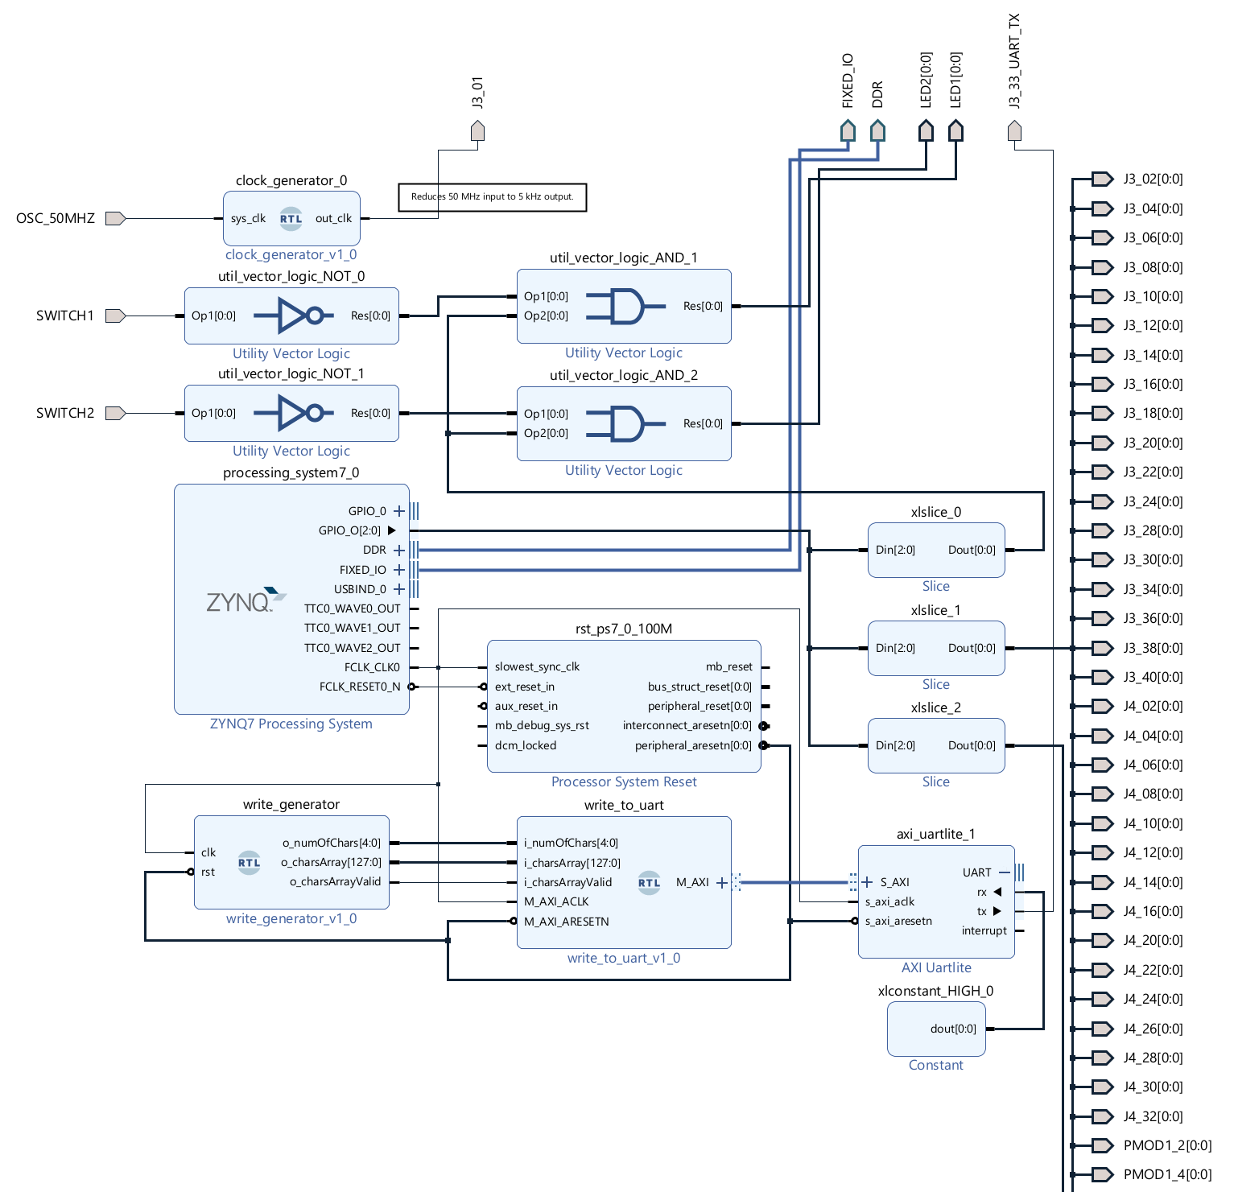
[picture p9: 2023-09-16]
board_demo_hw_and_sw/Vivado_Diagram.png

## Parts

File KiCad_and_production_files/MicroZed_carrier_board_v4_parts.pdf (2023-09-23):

Comment | Designator | Footprint | LCSC Part No (https://jlcpcb.com/parts) | Manuf. Part No | Comment
USB micro connector | CON1, CON2 | | C719023 (https://jlcpcb.com/partdetail/hrs_hirose-ZX62D_B_5P8_30/C719023) | ZX62D-B-5P8(30)
tactile switch | SW1,SW2 | | C445493 (https://jlcpcb.com/partdetail/447024-K2_1102DP_L3SW04/C445493) | K2-1102DP-L3SW-04
on/off switch | SW3 | | C2887259 (https://jlcpcb.com/partdetail/ShouHan-SS12D10G4071/C2887259) | SS12D10G4 071 (https://www.lcsc.com/product-detail/Slide-Switches_SHOU-HAN-SS12D10G4-071_C2887259.html)
100nF | C9,C12,C13,C15,C16,C17,C19,C20 | 0603 | C66501 (https://jlcpcb.com/partdetail/67585-CL10B104KO8NNNC/C66501) | CC0603KRX7R9BB104
22uF | C1,C2,C3,C4,C5,C6,C7,C8,C10,C11,C18 | 1206 | C5672 (https://jlcpcb.com/partdetail/6131-CL31A226KPHNNNE/C5672) | CL31A226KPHNNNE
10uF | C14 | 0603 | C19702 (https://jlcpcb.com/partdetail/20411-CL10A106KP8NNNC/C19702) | CL10A106KP8NNNC
DC-DC 3.3V 1.2A | REG1 | DFN-8-EP(2x2) | C485809 (https://jlcpcb.com/partdetail/TexasInstruments-TPS62082DSGR/C485809) | TPS62082DSGR (https://www.ti.com/product/TPS62082?keyMatch=TPS62082DSGR&tisearch=search-everything&usecase=OPN)
2.6A 1uH ±20% 4.2A | L1 | 0806 | C2913752 (https://jlcpcb.com/partdetail/ChilisinElec-BDHH002016101R0MDB/C2913752) | BDHH002016101R0MDB | datasheet of REG1 recommends XFL3012-102MEB, but that is not available in JLCPCB library
MOSFET | Q2,Q3,Q4 | SOT-23 | C400505 (https://jlcpcb.com/partdetail/Yangzhou_Yangjie_ElecTech-BSS138/C400505) | BSS138
3K92 1% | R8 | 0603 | C170585 (https://jlcpcb.com/partdetail/Walsin_TechCorp-WR06X3921FTL/C170585) | WR06X3921FTL
680R 1% | R11, R16 | 0603 | C23228 (https://jlcpcb.com/partdetail/23955-0603WAF6800T5E/C23228) | 0603WAF6800T5E
430R 1% | R14 | 0603 | C23170 (https://jlcpcb.com/partdetail/23897-0603WAF4300T5E/C23170) | 0603WAF4300T5E
1K 1% | R1,R5,R6,R9 | 0603 | C21190 (https://jlcpcb.com/partdetail/21904-0603WAF1001T5E/C21190) | 0603WAF1001T5E
220R 1% | R3 | 0603 | C22962 (https://jlcpcb.com/partdetail/23689-0603WAF2200T5E/C22962) | 0603WAF2200T5E
1.5K 1% | R10 | 0603 | C22843 (https://jlcpcb.com/partdetail/23570-0603WAF1501T5E/C22843) | 0603WAF1501T5E
3K 1% | R12 | 0603 | C4211 (https://jlcpcb.com/partdetail/4618-0603WAF3001T5E/C4211) | 0603WAF3001T5E
100K 1% | R23 | 0603 | C25803 (https://jlcpcb.com/partdetail/26546-0603WAF1003T5E/C25803) | 0603WAF1003T5E
100R | R2,R19,R22 | 0603 | C22775 (https://jlcpcb.com/partdetail/23502-0603WAF1000T5E/C22775) | 0603WAF1000T5E
300R | R4 | 0603 | C23025 (https://jlcpcb.com/partdetail/23752-0603WAF3000T5E/C23025) | 0603WAF3000T5E
3.3K 1% | R20,R27 | 0603 | C22978 (https://jlcpcb.com/partdetail/23705-0603WAF3301T5E/C22978) | 0603WAF3301T5E
180k | R13 | 0603 | C22827 (https://jlcpcb.com/partdetail/23554-0603WAF1803T5E/C22827) | 0603WAF1803T5E
1K54 | R26 | 0603 | C100784 (https://jlcpcb.com/partdetail/LizElec-CR0603FA1541G/C100784) | CR0603FA1541G
10K | R7 | 0603 | C25804 (https://jlcpcb.com/partdetail/26547-0603WAF1002T5E/C25804) | 0603WAF1002T5E
Shotky diode | D5, D8 | SOT-23 | C37704 (https://jlcpcb.com/partdetail/Nexperia-BAT54C215/C37704) | BAT54C,215
2.5V Ref | U2 | SOT-23-3 | C411753 (https://jlcpcb.com/partdetail/Pjsemi-TL431A/C411753) | TL431A PJSEMI | warning: original TI part has diferent pinout!
comparator | U1 | SOT-25-5 | C151034 (https://jlcpcb.com/partdetail/DiodesIncorporated-AP331AWG7/C151034) | AP331AWG-7
BergStak 100pos Plug height 4.7 mm | JX1,JX2 | | C2764776 (https://jlcpcb.com/partdetail/AmphenolIcc-61083101400LF/C2764776) | 61083-101400LF
level shifter | U3,U4 | TSSOP-20 | C53406 (https://jlcpcb.com/partdetail/TexasInstruments-TXB0108PWR/C53406) | TXB0108PWR
4K87 | R25 | 0603 | C2097544 (https://jlcpcb.com/partdetail/VishayIntertech-MCT06030C4871FP500/C2097544) | MCT06030C4871FP500 | for green 5V indicator LED
PL LED yellow | D1,D2 | 0805 | C2296 (https://jlcpcb.com/partdetail/Hubei_KentoElec-17_21SUYCTR8/C2296) | 17-21SUYC/TR8
150R 1% | R17,R18 | 0603 | C22808 (https://jlcpcb.com/partdetail/23535-0603WAF1500T5E/C22808) | 0603WAF1500T5E | for yellow 3.3V indicator LED
±0.5ppm 50MHz oscillator | X1 | C2920832 (https://jlcpcb.com/partdetail/Xtaltq-NT0503DH3I507BN50/C2920832) | NT0503DH3I507BN50
Interface Chip USB/UART | U5 | SOP-16 | C14267 (https://jlcpcb.com/partdetail/wch_jiangsu_Qin_heng-CH340G/C14267) | CH340G | the same as used in https://www.sparkfun.com/products/14050
AND gate | U6 | X1-DFN1010-6 | C150443 (https://jlcpcb.com/partdetail/DiodesIncorporated-74LVC1G08FW57/C150443) | 74LVC1G08FW5-7
12MHz 15pF crystal | Y1 | SMD2520-4P | C2149206 (https://jlcpcb.com/partdetail/Jyje-2TJ412000UYGBC/C2149206) | 2TJ412000UYGBC
22pF for crystal | C21,C22 | 0402 | C881987 (https://jlcpcb.com/partdetail/945485-C0402C0G220J250NTB/C881987) | C0402C0G220J250NTB
LED green | D3,D4,D6 | 0603 | C2833058 (https://jlcpcb.com/partdetail/Baizou-BZ_C0603_G3F1/C2833058) | BZ-C0603-G3-F1 | power indicators, RX_to_FPGA
133R for green LED RX | R15 | 0402 | C4326496 (https://jlcpcb.com/partdetail/VishayIntertech-CRCW0402133RFKED/C4326496) | CRCW0402133RFKED
LED yellow for TX_from_FPGA | D7 | 0603 | C5151485 (https://jlcpcb.com/partdetail/Amicc-A_SP192YY3C_A014T/C5151485) | A-SP192YY3C-A01-4T
154R for yellow LED | R24 | 0603 | C365385 (https://jlcpcb.com/partdetail/Resi-ETCR0603F154RK9/C365385) | ETCR0603F154RK9

Following connectors are not part of BOM, i.e. not part of JLCPCB Assembly (they are intended for DIY hand soldering):

Comment | Designator | Manuf. Part No
38 pin header | J4 | SSW-119-01-F-D (https://export.farnell.com/samtec/ssw-119-01-f-d/connector-rcpt-38pos-2row-2-54mm/dp/3749718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)
52 pin header | J3 | SSQ-126-03-G-D (https://export.farnell.com/samtec/ssq-126-03-g-d/conn-rcpt-52pos-2row-2-54mm/dp/3550887?ost=ssq-126-03-g-d)
2 pin header, 6 mm | JP1 | 61300211121 (https://eu.mouser.com/ProductDetail/Wurth-Elektronik/61300211121?qs=t4813l51qx%252B1A5GYDQxPlw%3D%3D)
PMOD receptacle right angle | PMODH1,PMODH2,PMODH3 | SSQ-106-03-T-D-RA (https://cz.mouser.com/ProductDetail/Samtec/SSQ-106-03-T-D-RA?qs=rU5fayqh%252BE1H0AL8diG8QA%3D%3D)
PMOD receptacle straight | PMODV1,PMODV2,PMODV3 | Farnell SSQ-106-01-G-D (https://export.farnell.com/samtec/ssq-106-01-g-d/receptacle-2-54mm-dual-12way/dp/1668296?st=ssq-106-01-g-d)
Power connector 8 pin, 2 rows | J5,J6 | Farnell SSQ-104-02-G-D (https://export.farnell.com/samtec/ssq-104-02-g-d/connector-rcpt-8pos-2row-2-54mm/dp/3700974?st=ssq-104-02-g-d)
GND header for probes, 4 pin, 1 row | J2, J7 | Farnell TSW-104-14-L-S (https://export.farnell.com/samtec/tsw-104-14-l-s/header-2-54mm-tht-vert-4way/dp/3663506?st=tsw-104-14-l-s)

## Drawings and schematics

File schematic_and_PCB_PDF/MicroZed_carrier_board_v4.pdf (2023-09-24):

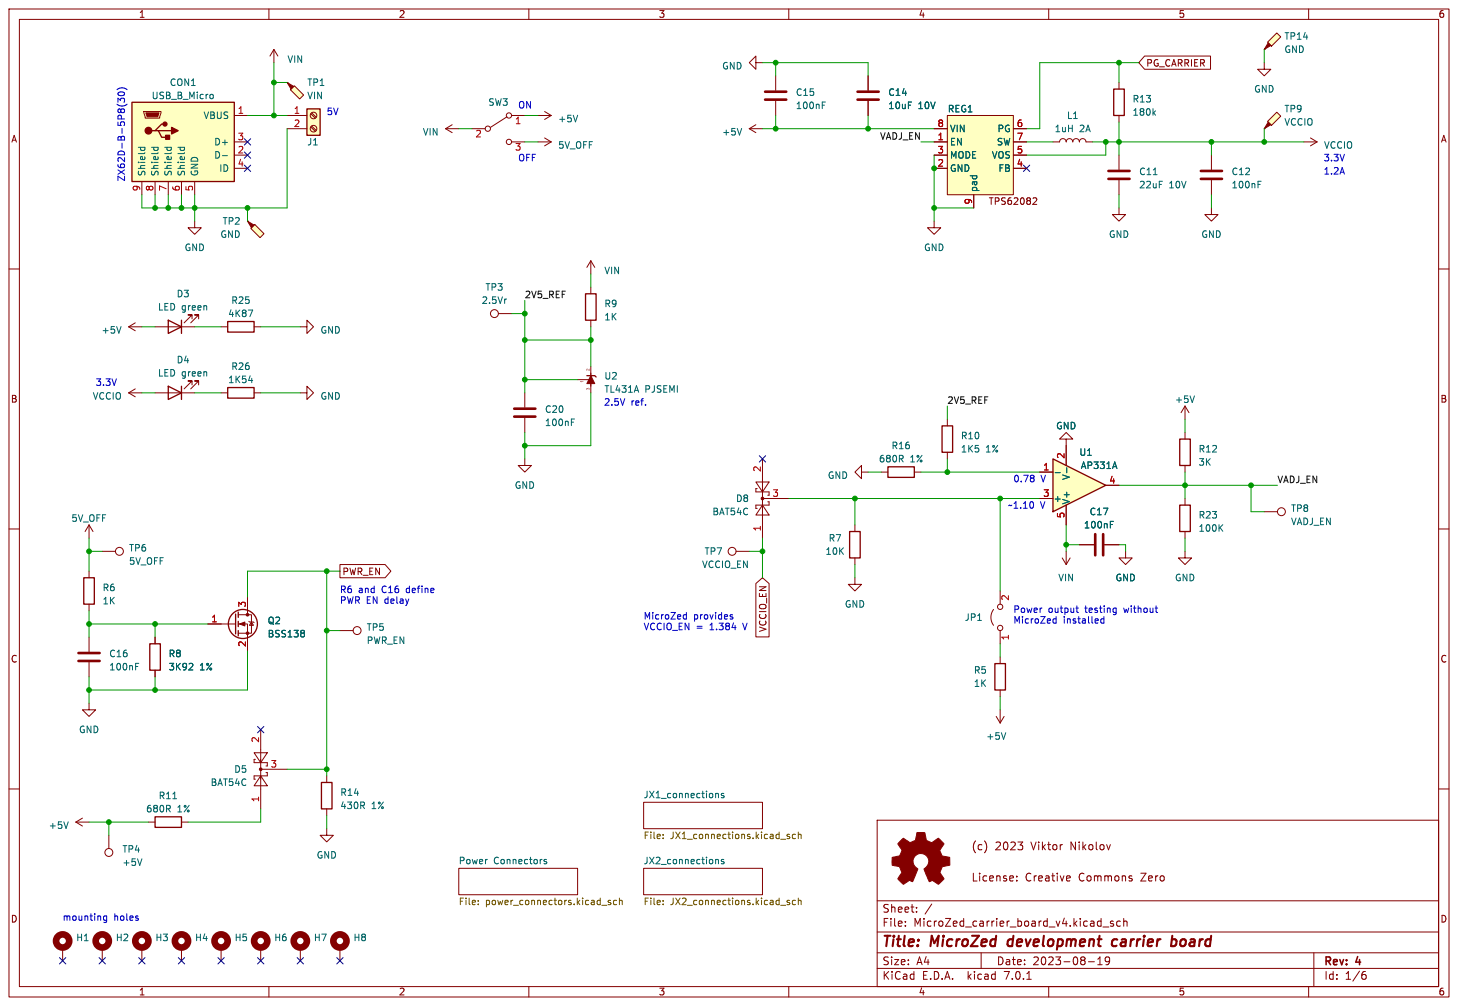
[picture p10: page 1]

Power output testing without MicroZed installed OFF ON

JX1_connections File: JX1_connections.kicad_sch Power Connectors File: power_connectors.kicad_sch

Id: 1/6 Title: MicroZed development carrier board

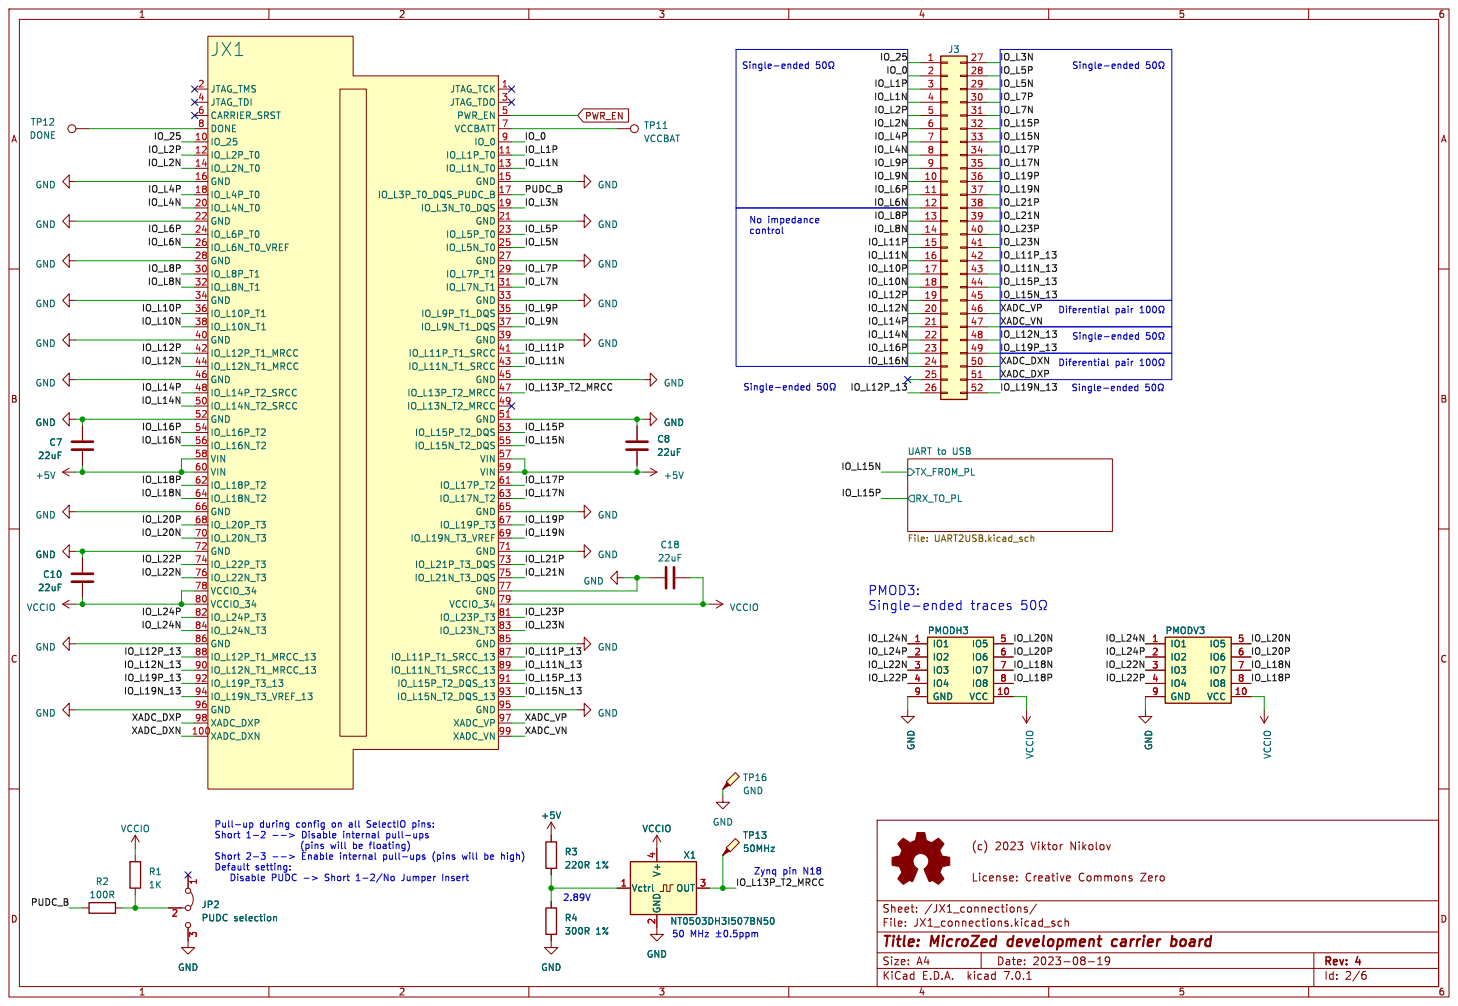
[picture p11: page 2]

TP12 DONE GND GND GND

File: JX1_connections.kicad_sch Sheet: /JX1_connections/ License: Creative Commons Zero

Id: 2/6 Title: MicroZed development carrier board

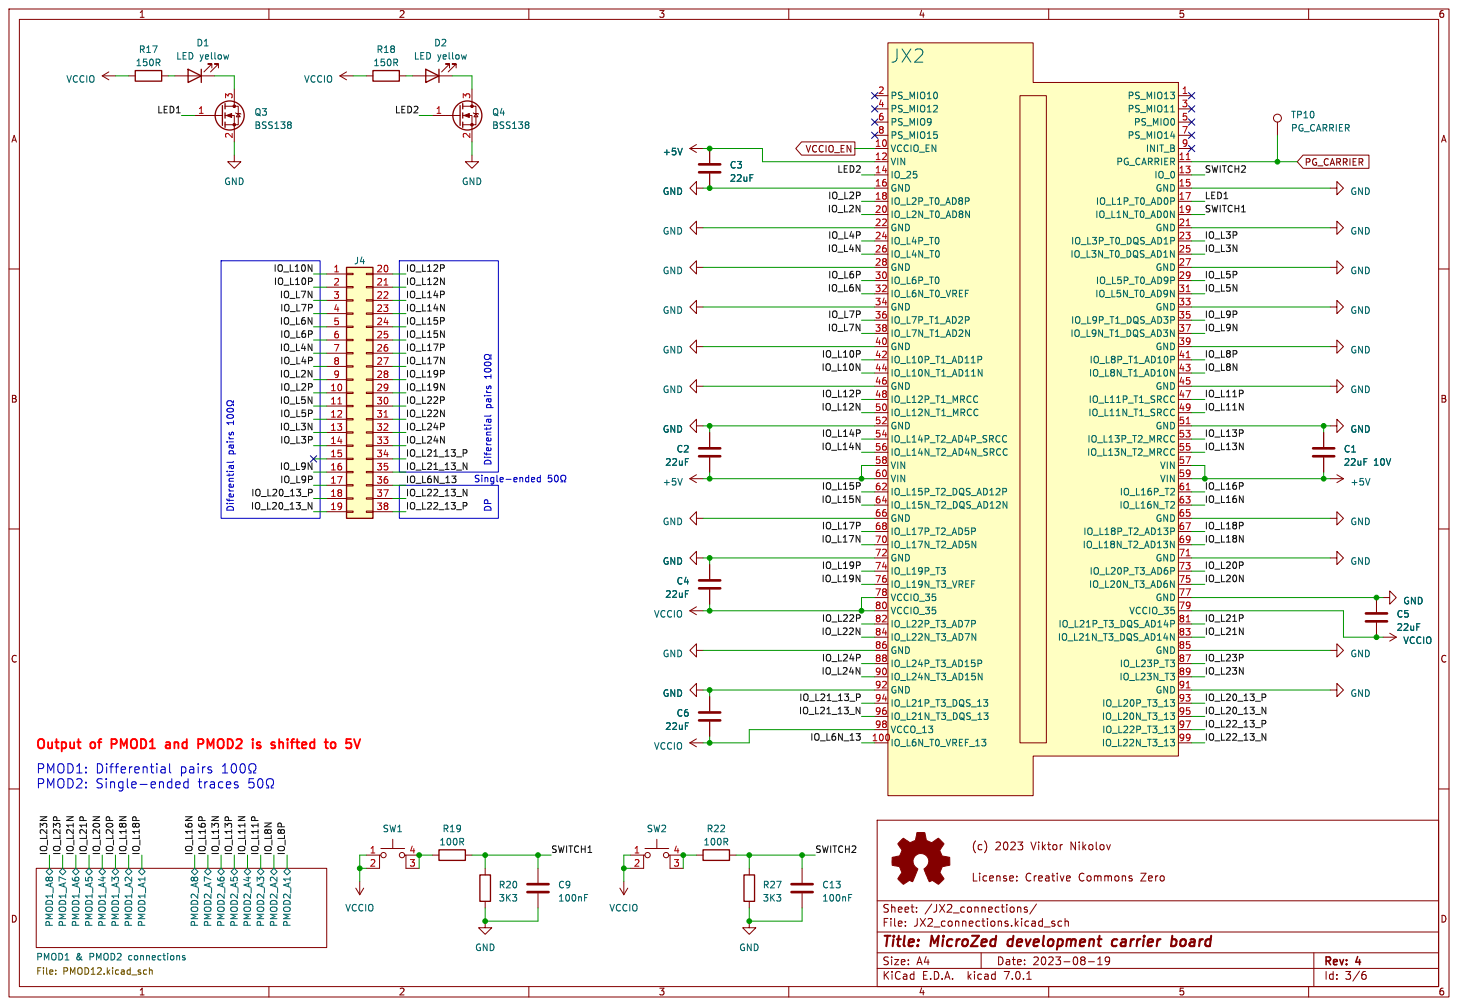
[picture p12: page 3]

GND GND GND GND GND

File: JX2_connections.kicad_sch Sheet: /JX2_connections/ License: Creative Commons Zero

Id: 3/6 Title: MicroZed development carrier board

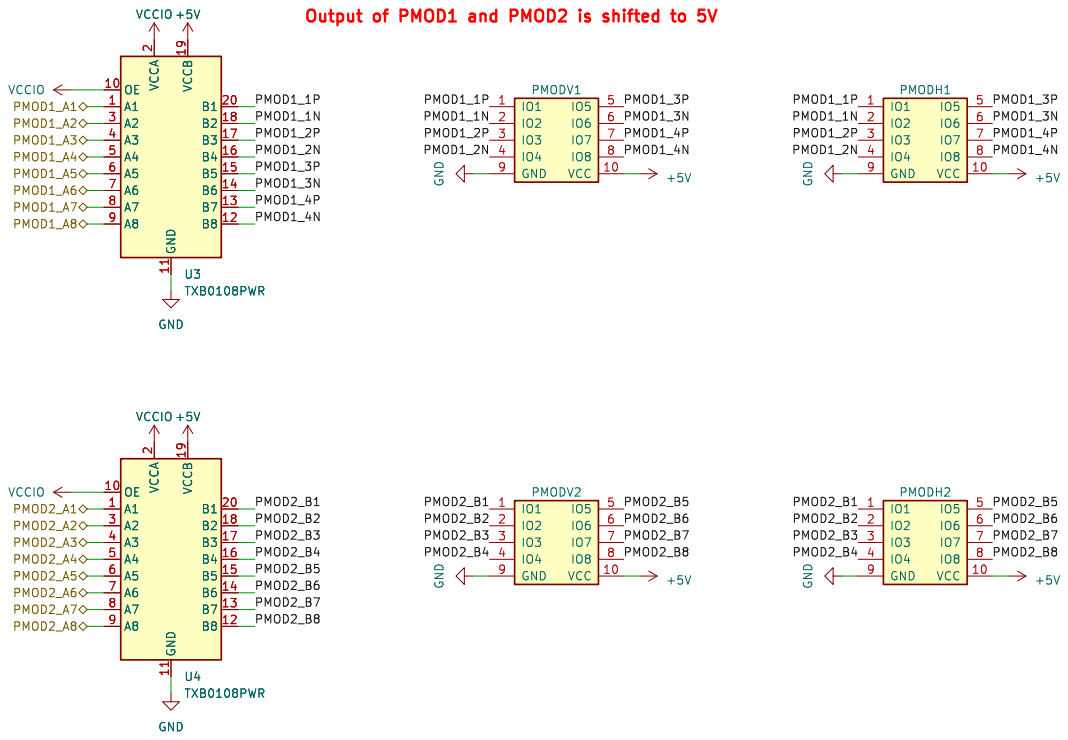
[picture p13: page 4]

PMOD1_2N Output of PMOD1 and PMOD2 is shifted to 5V

Id: 4/6 Title: MicroZed development carrier board

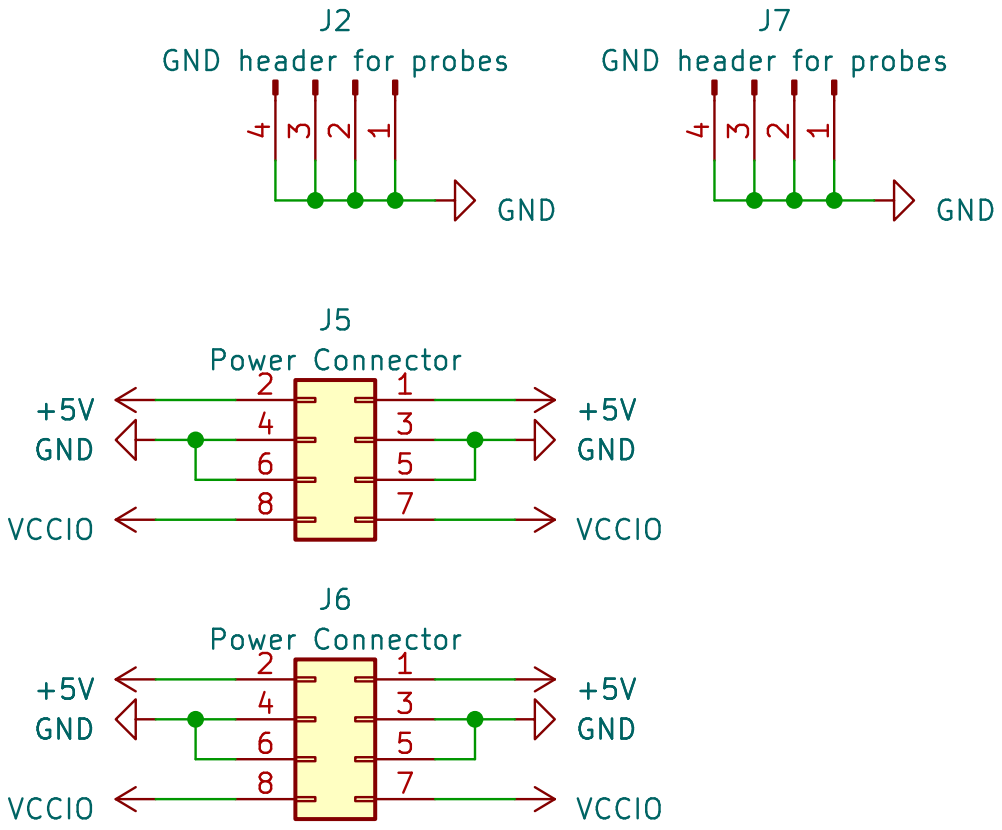
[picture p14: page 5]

J7 GND header for probes VCCIO

Id: 5/6 Title: MicroZed development carrier board

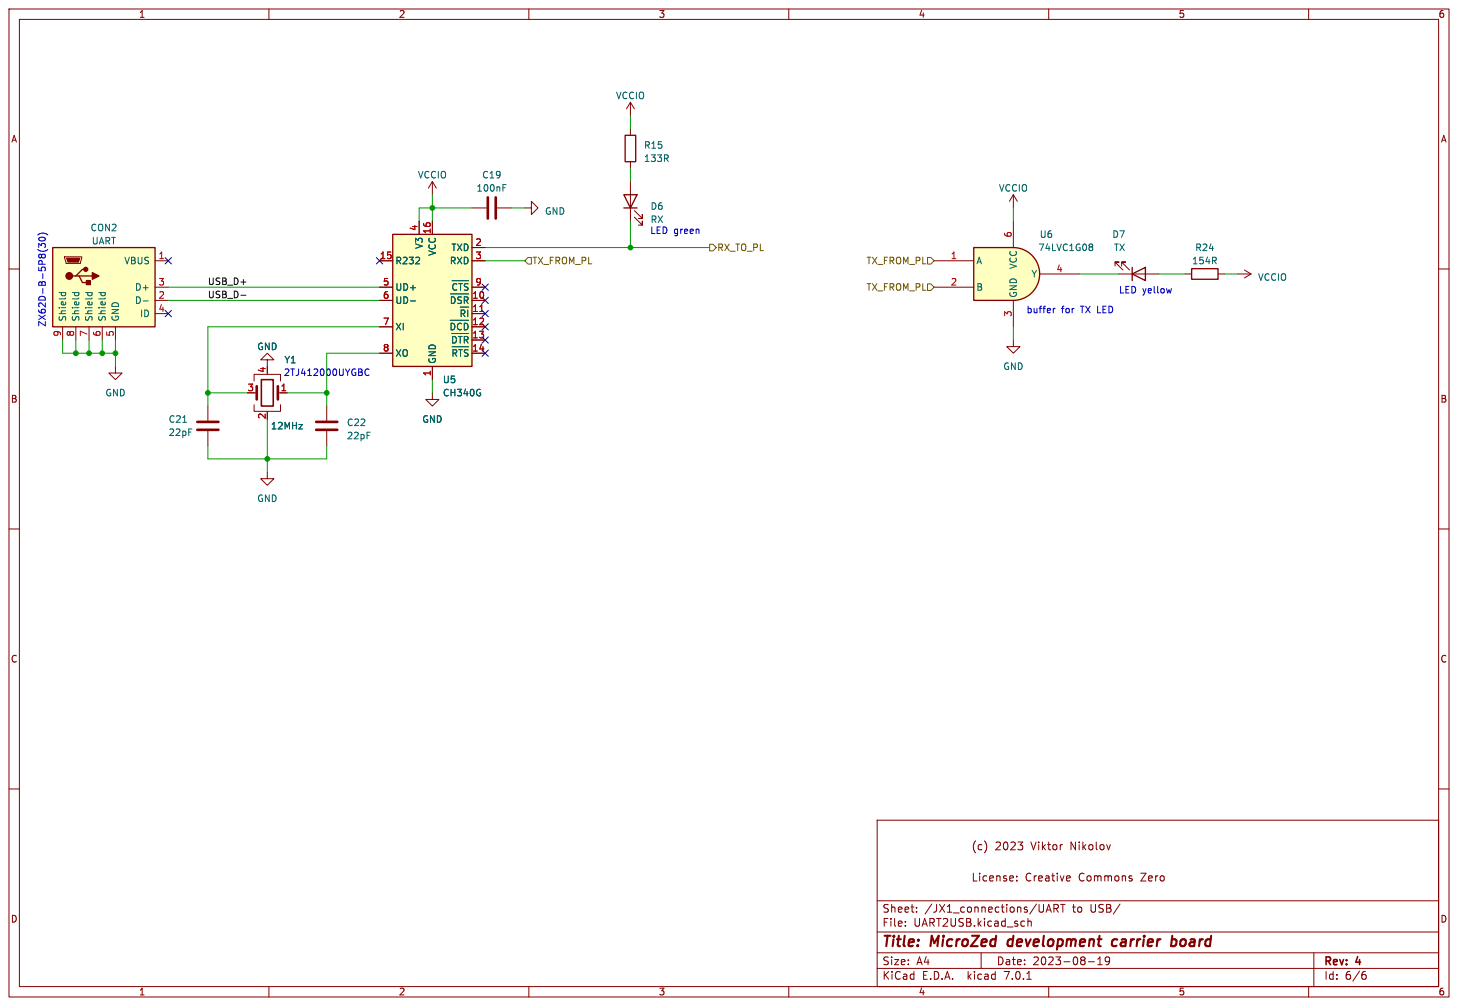
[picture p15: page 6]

4 UD+ 5 UD- 6 XI 7 XO 8 ~{CTS}9 Y1

1 ~{DSR} 10 ~{RI} 11 ~{DCD} 12 ~{DTR} 13 ~{RTS} 14 R232 15 VCC 16 TXD 2 RXD 3 V3

4 UD+ 5 UD- 6 XI 7 XO 8 ~{CTS}9 U5 CH340G

buffer for TX LED

Id: 6/6 Title: MicroZed development carrier board

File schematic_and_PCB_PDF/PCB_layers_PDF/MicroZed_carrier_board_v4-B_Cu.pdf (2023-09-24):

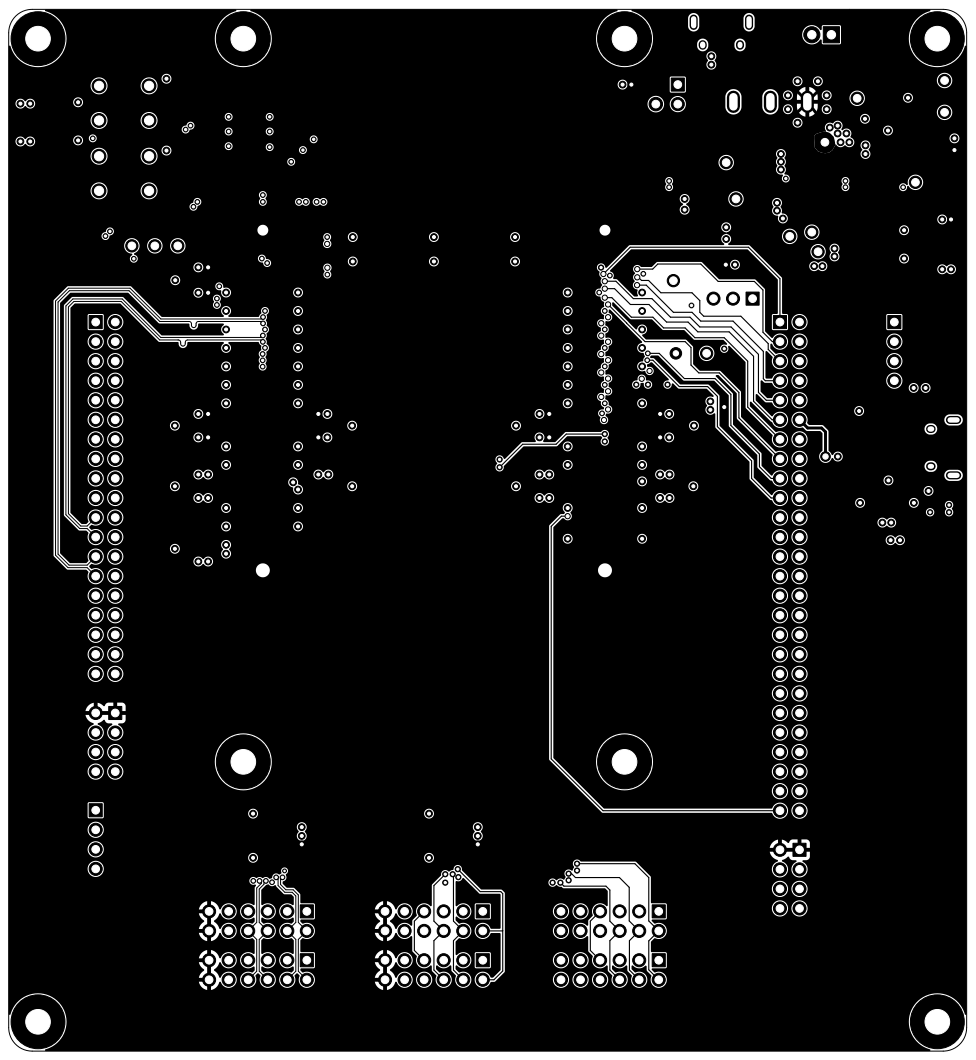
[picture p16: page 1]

Id: 1/1 Title: MicroZed development carrier board

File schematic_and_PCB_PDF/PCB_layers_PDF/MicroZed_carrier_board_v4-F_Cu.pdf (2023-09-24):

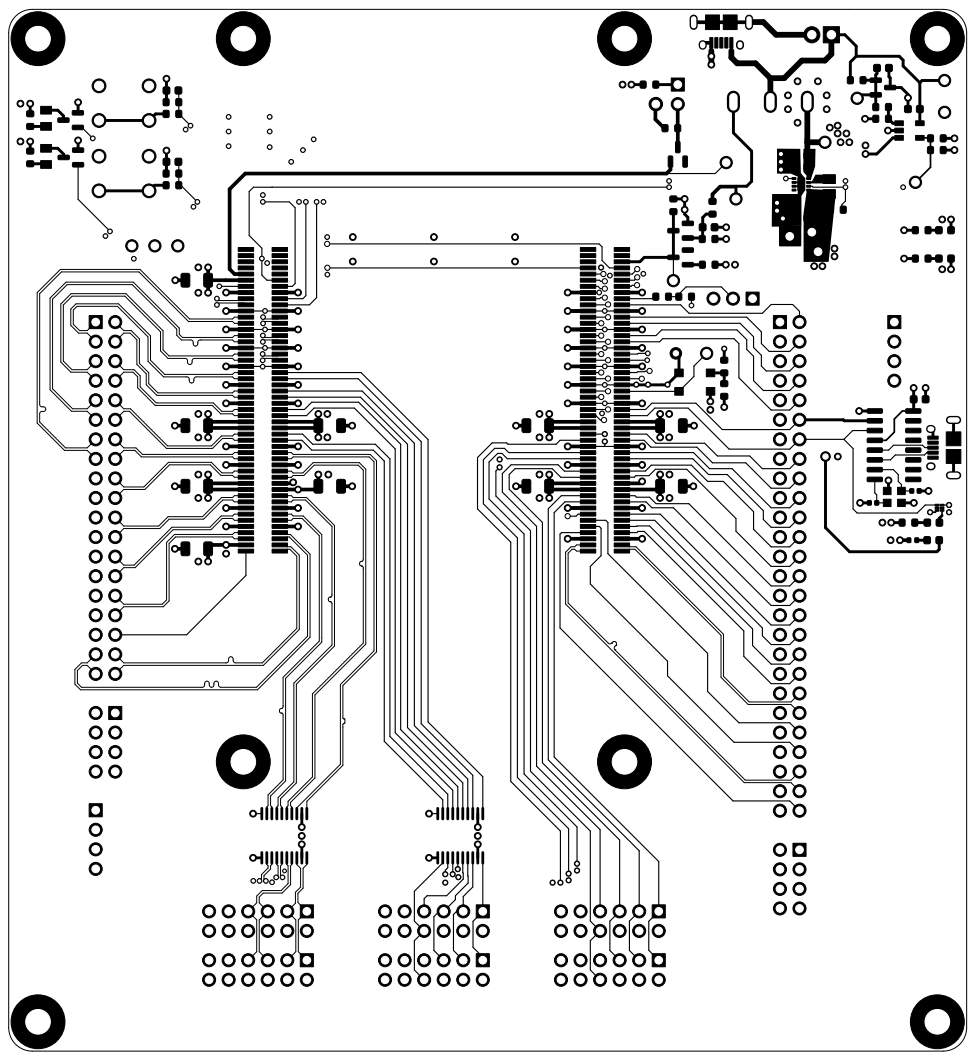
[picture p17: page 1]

Id: 1/1 Title: MicroZed development carrier board

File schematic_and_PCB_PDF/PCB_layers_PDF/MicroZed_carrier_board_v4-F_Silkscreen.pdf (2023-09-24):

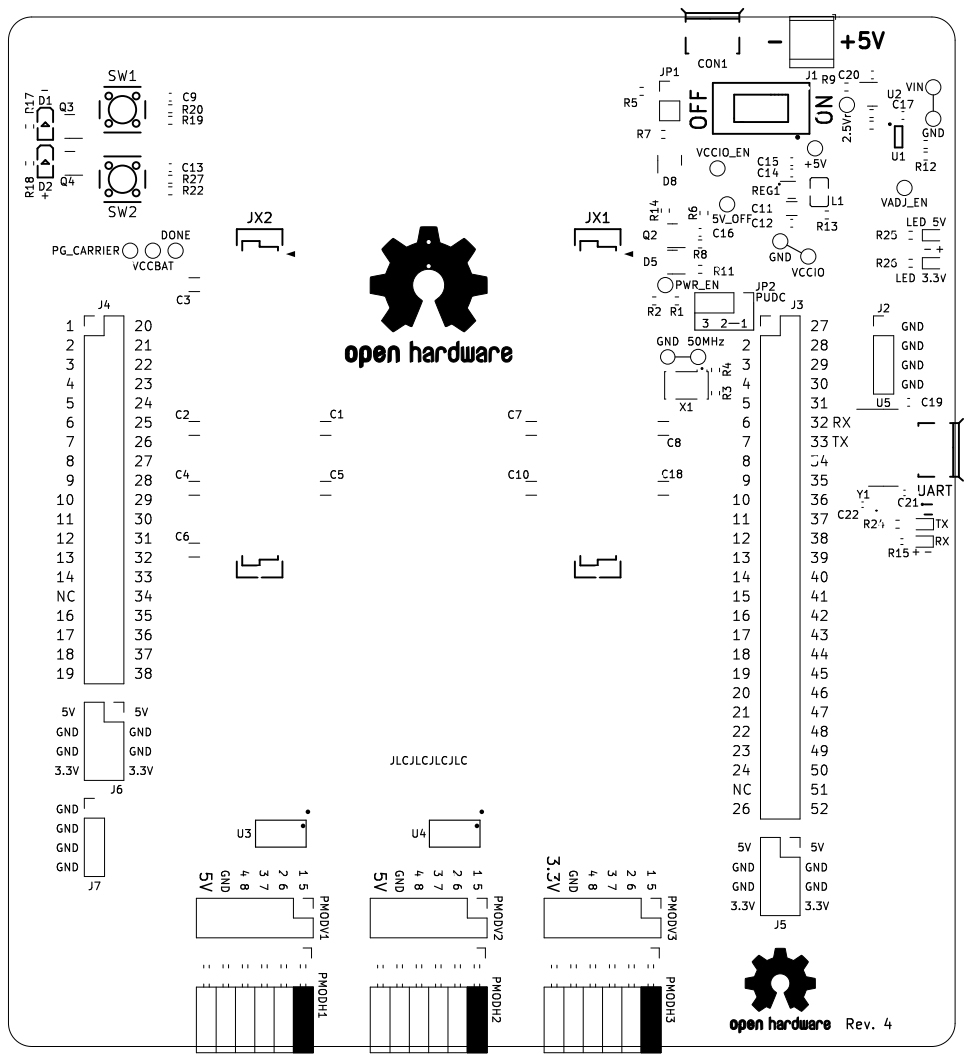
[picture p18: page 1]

Id: 1/1 Title: MicroZed development carrier board

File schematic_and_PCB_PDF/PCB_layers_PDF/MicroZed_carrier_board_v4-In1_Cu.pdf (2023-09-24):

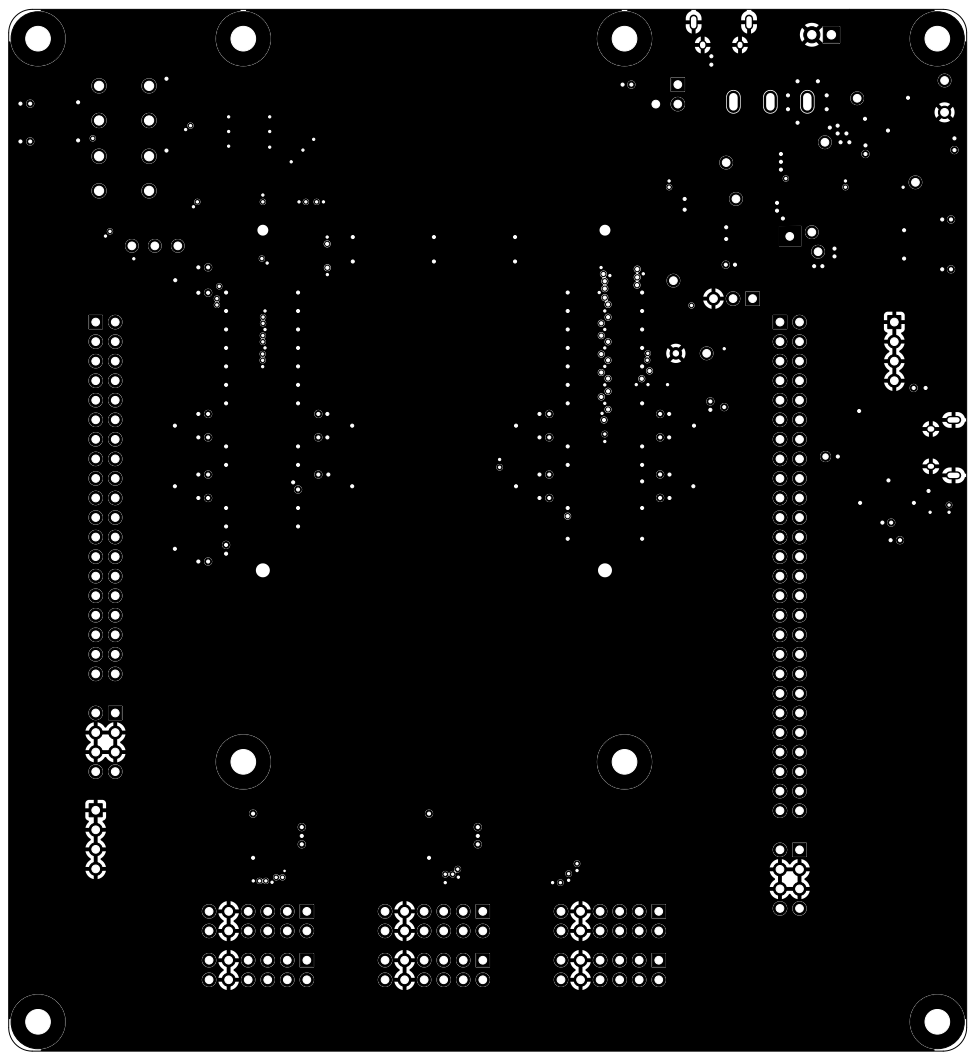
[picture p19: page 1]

Id: 1/1 Title: MicroZed development carrier board

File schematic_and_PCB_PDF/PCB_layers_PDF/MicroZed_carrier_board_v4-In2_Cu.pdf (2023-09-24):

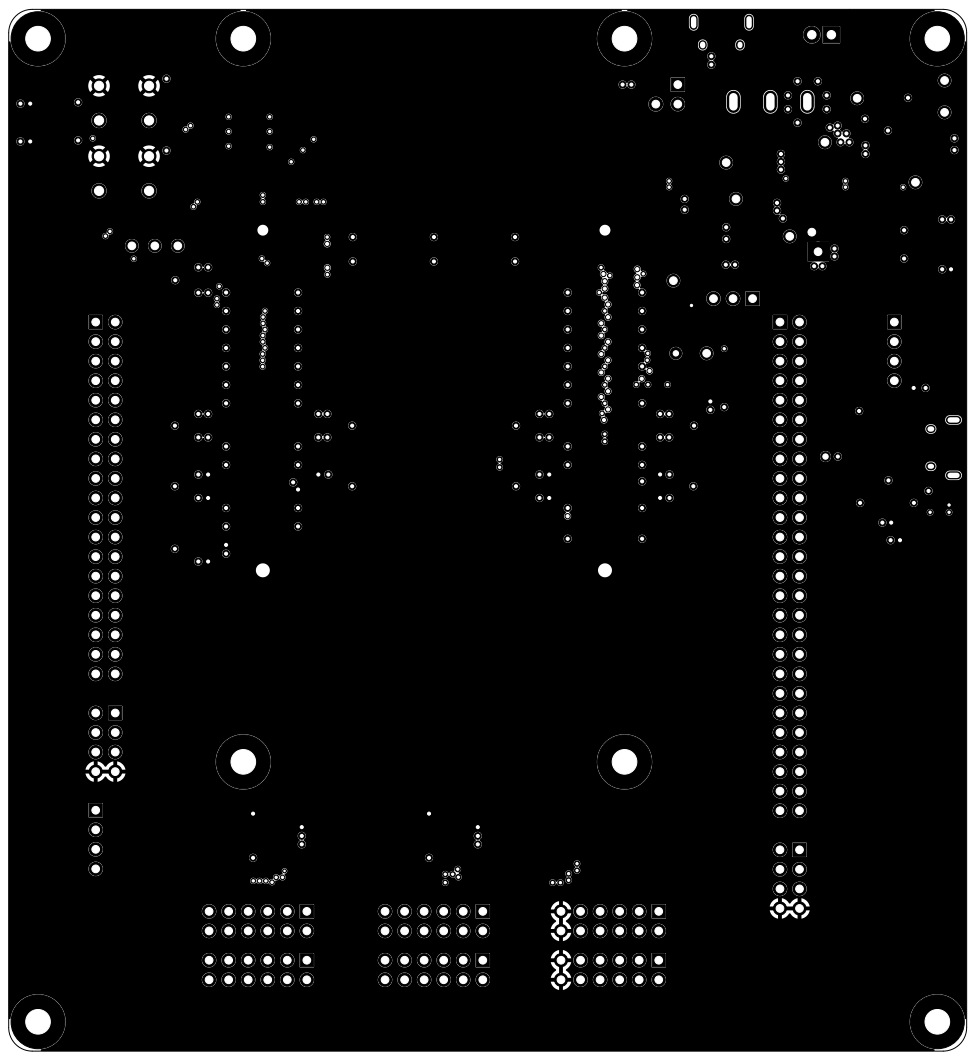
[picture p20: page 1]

Id: 1/1 Title: MicroZed development carrier board

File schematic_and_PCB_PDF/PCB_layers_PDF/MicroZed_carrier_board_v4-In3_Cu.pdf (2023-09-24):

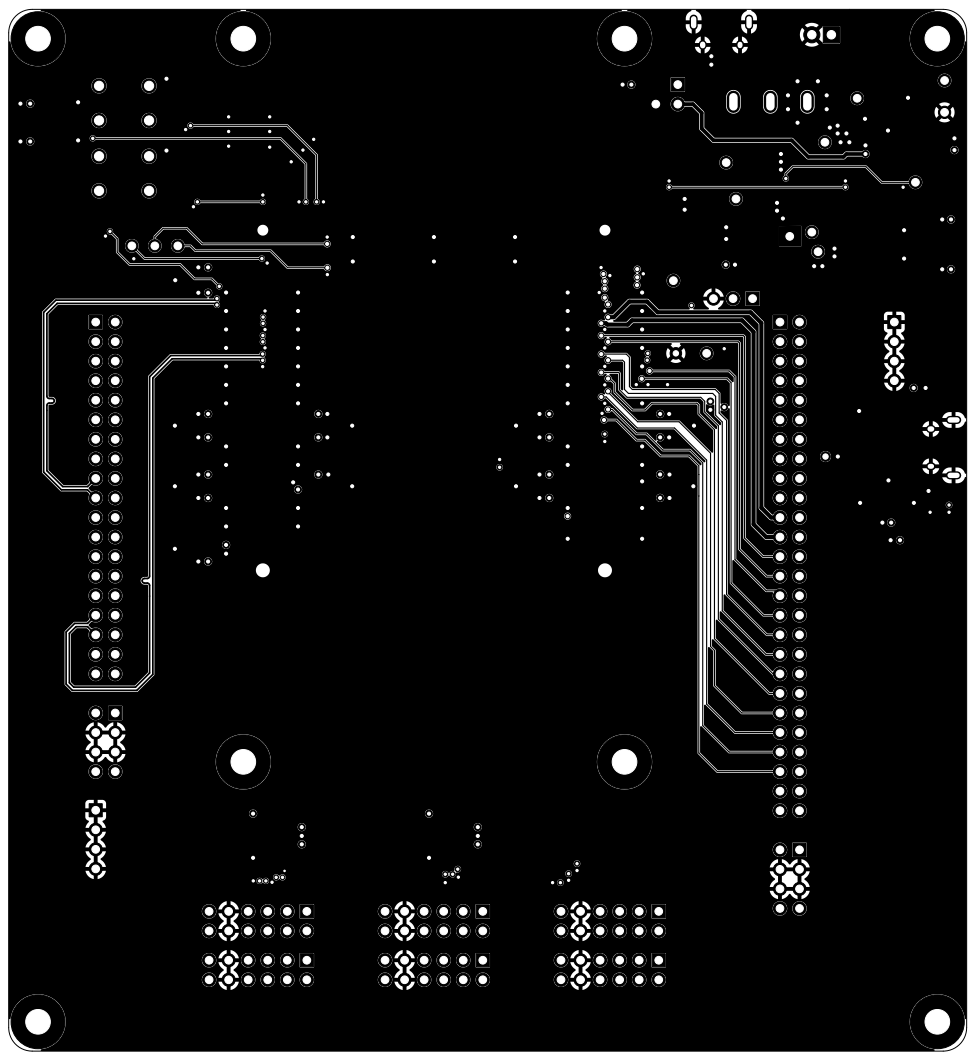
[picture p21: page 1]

Id: 1/1 Title: MicroZed development carrier board

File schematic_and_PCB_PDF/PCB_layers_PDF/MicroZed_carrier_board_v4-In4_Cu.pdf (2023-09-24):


Id: 1/1 Title: MicroZed development carrier board

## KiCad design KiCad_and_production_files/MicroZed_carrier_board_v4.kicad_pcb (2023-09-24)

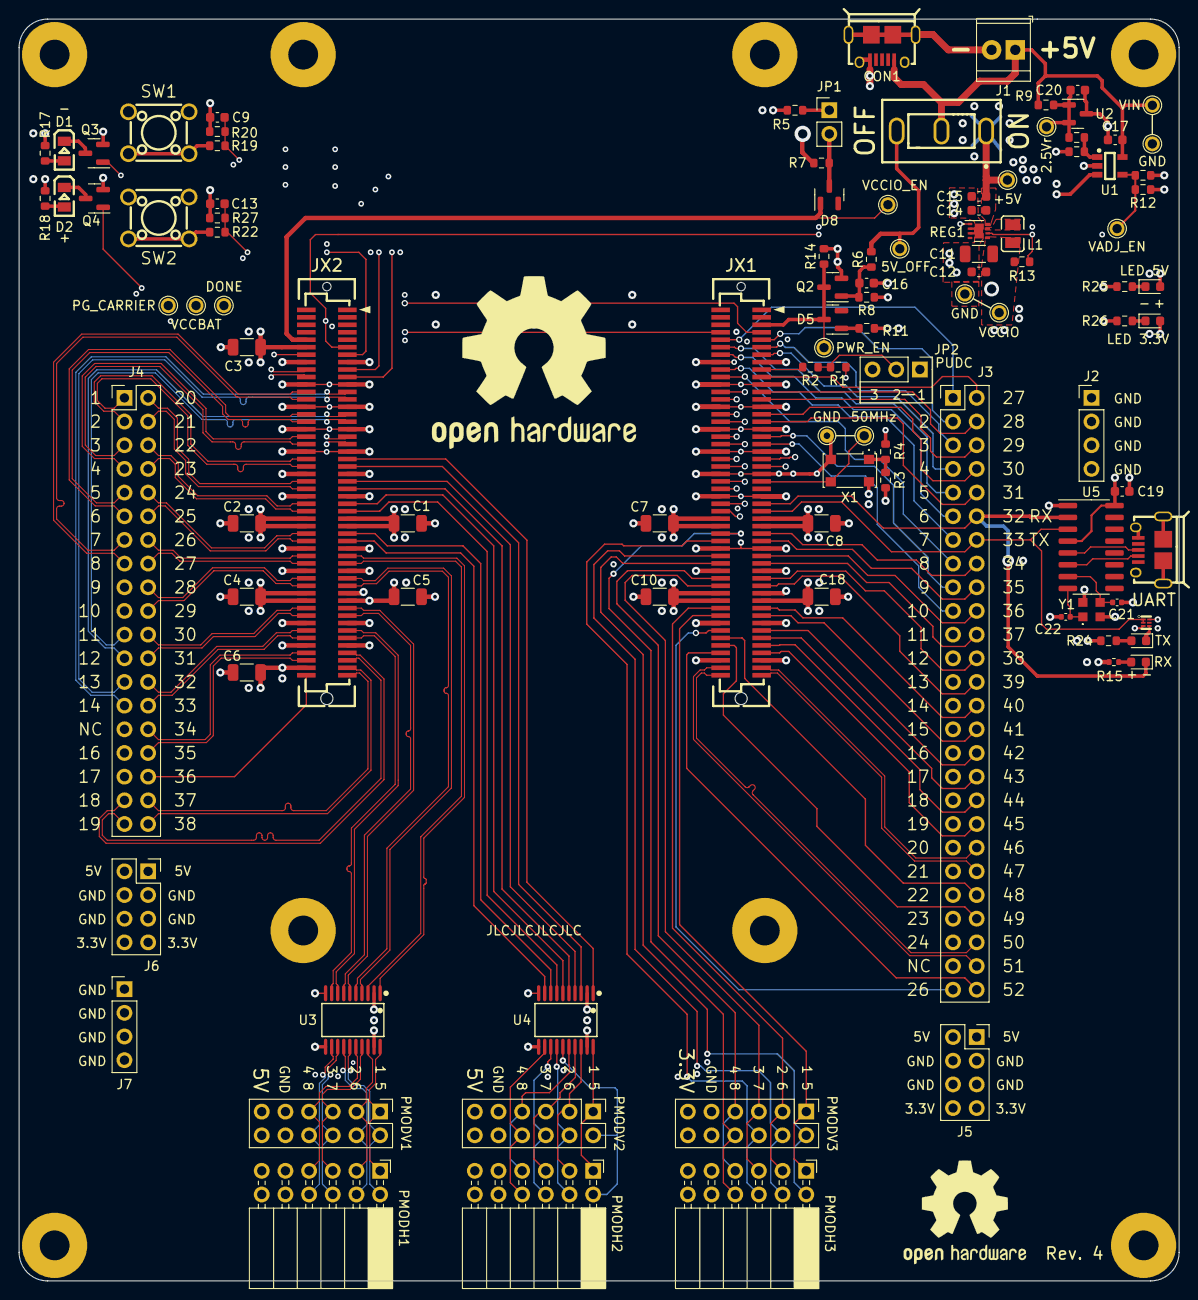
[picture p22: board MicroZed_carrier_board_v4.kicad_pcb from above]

Board: 6 copper layers, 124.5 x 135.4 mm, 116 parts (0 on the bottom side), 169 nets.

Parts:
C1, C11: 22uF 10V; C_1206_3216Metric
C2, C3, C4, C5, C6, C7, C8, C10, C18: 22uF; C_1206_3216Metric
C9, C12, C13, C15, C16, C17, C19, C20: 100nF; C_0603_1608Metric
C14: 10uF 10V; C_0603_1608Metric
C21, C22: 22pF; C_0402_1005Metric
CON1: USB_B_Micro; MICRO-USB-SMD_HRS-ZX62D-B-5P830
CON2: UART; MICRO-USB-SMD_HRS-ZX62D-B-5P830
D1, D2: LED yellow; LED0805
D3, D4: LED green; LED_0603_1608Metric
D5, D8: BAT54C; SOT-23
D6: RX; LED_0603_1608Metric
D7: TX; LED_0603_1608Metric
H1, H2, H3, H4, H5, H6, H7, H8: MountingHole_3.2mm_Pad_7mm
J1: Screw_Terminal_01x02; TerminalBlock_TE_282834-2_1x02_P2.54mm_Horizontal
J2, J7: GND header for probes; PinHeader_1x04_P2.54mm_Vertical
J3: Conn_02x26_Top_Bottom; PinSocket_2x26_P2.54mm_Top_Bottom_nums
J4: Conn_02x19_Top_Bottom; PinSocket_2x19_P2.54mm_Top_Bottom_nums
J5, J6: Power Connector; PinSocket_2x04_P2.54mm_Vertical
JP1: Jumper_2_Open; PinHeader_1x02_P2.54mm_Vertical
JP2: PUDC selection; PinHeader_1x03_P2.54mm_Vertical
JX1, JX2: BergStak-100pos-plug-61083-101400
L1: 1uH 2A; Inductor-0806_L2.0-W1.6-1
OSHW-Logo: OSHW-Logo2_14.6x12mm_SilkScreen
OpenHW logo: OSHW-Logo2_24.3x20mm_SilkScreen
PMODH1, PMODH2, PMODH3: PMOD_Socket_Horizontal
PMODV1, PMODV2, PMODV3: PMOD_Socket_Vertical
Q2, Q3, Q4: BSS138; SOT-23
R1, R5, R6, R9: 1K; R_0603_1608Metric
R2, R19, R22: 100R; R_0603_1608Metric
R3: 220R 1%; R_0603_1608Metric
R4: 300R 1%; R_0603_1608Metric
R7: 10K; R_0603_1608Metric
R8: 3K92 1%; R_0603_1608Metric
R10: 1K5 1%; R_0603_1608Metric
R11, R16: 680R 1%; R_0603_1608Metric
R12: 3K; R_0603_1608Metric
R13: 180k; R_0603_1608Metric
R14: 430R 1%; R_0603_1608Metric
R15: 133R; R_0402_1005Metric
R17, R18: 150R; R_0603_1608Metric
R20, R27: 3K3; R_0603_1608Metric
R23: 100K; R_0603_1608Metric
R24: 154R; R_0603_1608Metric
R25: 4K87; R_0603_1608Metric
R26: 1K54; R_0603_1608Metric
REG1: TPS62082DSGR; WSON-8-1EP_2x2mm_P0.5mm_EP0.9x1.6mm
SW1, SW2: SW_MEC_5E; Switch-TH_4P-L6.0-W6.0-P4.50-LS6.5
SW3: SW_SPDT; Switch_SS12D10G4
TP1: VIN; TestPoint__Drill1.0mm
TP2, TP14: GND; TestPoint__Drill1.0mm
TP3: 2.5Vr; TestPoint__Drill1.0mm
TP4: +5V; TestPoint__Drill1.0mm
TP5: PWR_EN; TestPoint__Drill1.0mm
TP6: 5V_OFF; TestPoint__Drill1.0mm
TP7: VCCIO_EN; TestPoint__Drill1.0mm
TP8: VADJ_EN; TestPoint__Drill1.0mm
TP9: VCCIO; TestPoint__Drill1.0mm
TP10: PG_CARRIER; TestPoint__Drill1.0mm
TP11: VCCBAT; TestPoint__Drill1.0mm
TP12: DONE; TestPoint__Drill1.0mm
TP13: 50MHz; TestPoint__Drill1.0mm
TP16: GND; TestPoint_THTPad_D1.5mm_Drill0.7mm
U1: AP331A; SOT-25-5_L3.0-W1.8-P0.95-LS3.0-BR
U2: TL431A PJSEMI; SOT-23
U3, U4: TXB0108PWR; TSSOP-20_L6.5-W4.4-P0.65-LS6.4-BL
U5: CH340G; SOP-16_3.9x9.9mm_P1.27mm
U6: 74LVC1G08; X1-DFN1010-6_L1.0-W1.0-P0.35-BL
X1: NT0503DH3I507BN50; Oscillator_SMD_5.1x3.3mm
Y1: 12MHz; Crystal SMD2520-4P

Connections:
5V_OFF: R6.2, SW3.3 (C), TP6.1
+5V: C1.1, C2.1, C3.1, C7.1, C8.1, C14.1, C15.2, D3.2 (A), J5.1, J5.2, J6.1, J6.2, JX1.57 (VIN), JX1.58 (VIN), JX1.59 (VIN), JX1.60 (VIN), JX2.12 (VIN), JX2.57 (VIN), JX2.58 (VIN), JX2.59 (VIN), JX2.60 (VIN), PMODH1.10 (VCC), PMODH2.10 (VCC), PMODV1.10 (VCC), PMODV2.10 (VCC), R3.1, R5.2, R11.2, R12.1, REG1.8 (VIN), SW3.1 (A), TP4.1, U3.19 (VCCB), U4.19 (VCCB)
/2V5_REF: C20.1, R9.1, R10.1, TP3.1, U2.1 (REF), U2.2 (K)
/JX1_connections/IO_0: J3.2, JX1.9 (IO_0)
/JX1_connections/IO_25: J3.1, JX1.10 (IO_25)
/JX1_connections/IO_L1N: J3.4, JX1.13 (IO_L1N_T0)
/JX1_connections/IO_L1P: J3.3, JX1.11 (IO_L1P_T0)
/JX1_connections/IO_L2N: J3.6, JX1.14 (IO_L2N_T0)
/JX1_connections/IO_L2P: J3.5, JX1.12 (IO_L2P_T0)
/JX1_connections/IO_L3N: J3.27, JX1.19 (IO_L3N_T0_DQS)
/JX1_connections/IO_L4N: J3.8, JX1.20 (IO_L4N_T0)
/JX1_connections/IO_L4P: J3.7, JX1.18 (IO_L4P_T0)
/JX1_connections/IO_L5N: J3.29, JX1.25 (IO_L5N_T0)
/JX1_connections/IO_L5P: J3.28, JX1.23 (IO_L5P_T0)
/JX1_connections/IO_L6N: J3.12, JX1.26 (IO_L6N_T0_VREF)
/JX1_connections/IO_L6P: J3.11, JX1.24 (IO_L6P_T0)
/JX1_connections/IO_L7N: J3.31, JX1.31 (IO_L7N_T1)
/JX1_connections/IO_L7P: J3.30, JX1.29 (IO_L7P_T1)
/JX1_connections/IO_L8N: J3.14, JX1.32 (IO_L8N_T1)
/JX1_connections/IO_L8P: J3.13, JX1.30 (IO_L8P_T1)
/JX1_connections/IO_L9N: J3.10, JX1.37 (IO_L9N_T1_DQS)
/JX1_connections/IO_L9P: J3.9, JX1.35 (IO_L9P_T1_DQS)
/JX1_connections/IO_L10N: J3.18, JX1.38 (IO_L10N_T1)
/JX1_connections/IO_L10P: J3.17, JX1.36 (IO_L10P_T1)
/JX1_connections/IO_L11N: J3.16, JX1.43 (IO_L11N_T1_SRCC)
/JX1_connections/IO_L11N_13: J3.43, JX1.89 (IO_L11N_T1_SRCC_13)
/JX1_connections/IO_L11P: J3.15, JX1.41 (IO_L11P_T1_SRCC)
/JX1_connections/IO_L11P_13: J3.42, JX1.87 (IO_L11P_T1_SRCC_13)
/JX1_connections/IO_L12N: J3.20, JX1.44 (IO_L12N_T1_MRCC)
/JX1_connections/IO_L12N_13: J3.48, JX1.90 (IO_L12N_T1_MRCC_13)
/JX1_connections/IO_L12P: J3.19, JX1.42 (IO_L12P_T1_MRCC)
/JX1_connections/IO_L12P_13: J3.26, JX1.88 (IO_L12P_T1_MRCC_13)
/JX1_connections/IO_L13P_T2_MRCC: JX1.47 (IO_L13P_T2_MRCC), TP13.1, X1.3 (OUT)
/JX1_connections/IO_L14N: J3.22, JX1.50 (IO_L14N_T2_SRCC)
/JX1_connections/IO_L14P: J3.21, JX1.48 (IO_L14P_T2_SRCC)
/JX1_connections/IO_L15N: J3.33, JX1.55 (IO_L15N_T2_DQS), U5.3 (RXD), U6.1 (A), U6.2 (B)
/JX1_connections/IO_L15N_13: J3.45, JX1.93 (IO_L15N_T2_DQS_13)
/JX1_connections/IO_L15P: D6.1 (K), J3.32, JX1.53 (IO_L15P_T2_DQS), U5.2 (TXD)
/JX1_connections/IO_L15P_13: J3.44, JX1.91 (IO_L15P_T2_DQS_13)
/JX1_connections/IO_L16N: J3.24, JX1.56 (IO_L16N_T2)
/JX1_connections/IO_L16P: J3.23, JX1.54 (IO_L16P_T2)
/JX1_connections/IO_L17N: J3.35, JX1.63 (IO_L17N_T2)
/JX1_connections/IO_L17P: J3.34, JX1.61 (IO_L17P_T2)
/JX1_connections/IO_L18N: JX1.64 (IO_L18N_T2), PMODH3.7 (IO7), PMODV3.7 (IO7)
/JX1_connections/IO_L18P: JX1.62 (IO_L18P_T2), PMODH3.8 (IO8), PMODV3.8 (IO8)
/JX1_connections/IO_L19N: J3.37, JX1.69 (IO_L19N_T3_VREF)
/JX1_connections/IO_L19N_13: J3.52, JX1.94 (IO_L19N_T3_VREF_13)
/JX1_connections/IO_L19P: J3.36, JX1.67 (IO_L19P_T3)
/JX1_connections/IO_L19P_13: J3.49, JX1.92 (IO_L19P_T3_13)
/JX1_connections/IO_L20N: JX1.70 (IO_L20N_T3), PMODH3.5 (IO5), PMODV3.5 (IO5)
/JX1_connections/IO_L20P: JX1.68 (IO_L20P_T3), PMODH3.6 (IO6), PMODV3.6 (IO6)
/JX1_connections/IO_L21N: J3.39, JX1.75 (IO_L21N_T3_DQS)
/JX1_connections/IO_L21P: J3.38, JX1.73 (IO_L21P_T3_DQS)
/JX1_connections/IO_L22N: JX1.76 (IO_L22N_T3), PMODH3.3 (IO3), PMODV3.3 (IO3)
/JX1_connections/IO_L22P: JX1.74 (IO_L22P_T3), PMODH3.4 (IO4), PMODV3.4 (IO4)
/JX1_connections/IO_L23N: J3.41, JX1.83 (IO_L23N_T3)
/JX1_connections/IO_L23P: J3.40, JX1.81 (IO_L23P_T3)
/JX1_connections/IO_L24N: JX1.84 (IO_L24N_T3), PMODH3.1 (IO1), PMODV3.1 (IO1)
/JX1_connections/IO_L24P: JX1.82 (IO_L24P_T3), PMODH3.2 (IO2), PMODV3.2 (IO2)
/JX1_connections/PUDC_B: JX1.17 (IO_L3P_T0_DQS_PUDC_B), R2.2
/JX1_connections/UART to USB/USB_D+: CON2.3 (D+), U5.5 (UD+)
/JX1_connections/UART to USB/USB_D-: CON2.2 (D-), U5.6 (UD-)
/JX1_connections/XADC_DXN: J3.50, JX1.100 (XADC_DXN)
/JX1_connections/XADC_DXP: J3.51, JX1.98 (XADC_DXP)
/JX1_connections/XADC_VN: J3.47, JX1.99 (XADC_VN)
/JX1_connections/XADC_VP: J3.46, JX1.97 (XADC_VP)
/JX2_connections/IO_L2N: J4.9, JX2.20 (IO_L2N_T0_AD8N)
/JX2_connections/IO_L2P: J4.10, JX2.18 (IO_L2P_T0_AD8P)
/JX2_connections/IO_L3N: J4.13, JX2.25 (IO_L3N_T0_DQS_AD1N)
/JX2_connections/IO_L3P: J4.14, JX2.23 (IO_L3P_T0_DQS_AD1P)
/JX2_connections/IO_L4N: J4.7, JX2.26 (IO_L4N_T0)
/JX2_connections/IO_L4P: J4.8, JX2.24 (IO_L4P_T0)
/JX2_connections/IO_L5N: J4.11, JX2.31 (IO_L5N_T0_AD9N)
/JX2_connections/IO_L5P: J4.12, JX2.29 (IO_L5P_T0_AD9P)
/JX2_connections/IO_L6N: J4.5, JX2.32 (IO_L6N_T0_VREF)
/JX2_connections/IO_L6N_13: J4.36, JX2.100 (IO_L6N_T0_VREF_13)
/JX2_connections/IO_L6P: J4.6, JX2.30 (IO_L6P_T0)
/JX2_connections/IO_L7N: J4.3, JX2.38 (IO_L7N_T1_AD2N)
/JX2_connections/IO_L7P: J4.4, JX2.36 (IO_L7P_T1_AD2P)
/JX2_connections/IO_L8N: JX2.43 (IO_L8N_T1_AD10N), U4.3 (A2)
/JX2_connections/IO_L8P: JX2.41 (IO_L8P_T1_AD10P), U4.1 (A1)
/JX2_connections/IO_L9N: J4.16, JX2.37 (IO_L9N_T1_DQS_AD3N)
/JX2_connections/IO_L9P: J4.17, JX2.35 (IO_L9P_T1_DQS_AD3P)
/JX2_connections/IO_L10N: J4.1, JX2.44 (IO_L10N_T1_AD11N)
/JX2_connections/IO_L10P: J4.2, JX2.42 (IO_L10P_T1_AD11P)
/JX2_connections/IO_L11N: JX2.49 (IO_L11N_T1_SRCC), U4.5 (A4)
/JX2_connections/IO_L11P: JX2.47 (IO_L11P_T1_SRCC), U4.4 (A3)
/JX2_connections/IO_L12N: J4.21, JX2.50 (IO_L12N_T1_MRCC)
/JX2_connections/IO_L12P: J4.20, JX2.48 (IO_L12P_T1_MRCC)
/JX2_connections/IO_L13N: JX2.55 (IO_L13N_T2_MRCC), U4.7 (A6)
/JX2_connections/IO_L13P: JX2.53 (IO_L13P_T2_MRCC), U4.6 (A5)
/JX2_connections/IO_L14N: J4.23, JX2.56 (IO_L14N_T2_AD4N_SRCC)
/JX2_connections/IO_L14P: J4.22, JX2.54 (IO_L14P_T2_AD4P_SRCC)
/JX2_connections/IO_L15N: J4.25, JX2.64 (IO_L15N_T2_DQS_AD12N)
/JX2_connections/IO_L15P: J4.24, JX2.62 (IO_L15P_T2_DQS_AD12P)
/JX2_connections/IO_L16N: JX2.63 (IO_L16N_T2), U4.9 (A8)
/JX2_connections/IO_L16P: JX2.61 (IO_L16P_T2), U4.8 (A7)
/JX2_connections/IO_L17N: J4.27, JX2.70 (IO_L17N_T2_AD5N)
/JX2_connections/IO_L17P: J4.26, JX2.68 (IO_L17P_T2_AD5P)
/JX2_connections/IO_L18N: JX2.69 (IO_L18N_T2_AD13N), U3.3 (A2)
/JX2_connections/IO_L18P: JX2.67 (IO_L18P_T2_AD13P), U3.1 (A1)
/JX2_connections/IO_L19N: J4.29, JX2.76 (IO_L19N_T3_VREF)
/JX2_connections/IO_L19P: J4.28, JX2.74 (IO_L19P_T3)
/JX2_connections/IO_L20N: JX2.75 (IO_L20N_T3_AD6N), U3.5 (A4)
/JX2_connections/IO_L20P: JX2.73 (IO_L20P_T3_AD6P), U3.4 (A3)
/JX2_connections/IO_L20_13_N: J4.19, JX2.95 (IO_L20N_T3_13)
/JX2_connections/IO_L20_13_P: J4.18, JX2.93 (IO_L20P_T3_13)
/JX2_connections/IO_L21N: JX2.83 (IO_L21N_T3_DQS_AD14N), U3.7 (A6)
/JX2_connections/IO_L21P: JX2.81 (IO_L21P_T3_DQS_AD14P), U3.6 (A5)
/JX2_connections/IO_L21_13_N: J4.35, JX2.96 (IO_L21N_T3_DQS_13)
/JX2_connections/IO_L21_13_P: J4.34, JX2.94 (IO_L21P_T3_DQS_13)
/JX2_connections/IO_L22N: J4.31, JX2.84 (IO_L22N_T3_AD7N)
/JX2_connections/IO_L22P: J4.30, JX2.82 (IO_L22P_T3_AD7P)
/JX2_connections/IO_L22_13_N: J4.37, JX2.99 (IO_L22N_T3_13)
/JX2_connections/IO_L22_13_P: J4.38, JX2.97 (IO_L22P_T3_13)
/JX2_connections/IO_L23N: JX2.89 (IO_L23N_T3), U3.9 (A8)
/JX2_connections/IO_L23P: JX2.87 (IO_L23P_T3), U3.8 (A7)
/JX2_connections/IO_L24N: J4.33, JX2.90 (IO_L24N_T3_AD15N)
/JX2_connections/IO_L24P: J4.32, JX2.88 (IO_L24P_T3_AD15P)
/JX2_connections/LED1: JX2.17 (IO_L1P_T0_AD0P), Q3.1 (G)
/JX2_connections/LED2: JX2.14 (IO_25), Q4.1 (G)
/JX2_connections/PMOD1 & PMOD2 connections/PMOD1_1N: PMODH1.2 (IO2), PMODV1.2 (IO2), U3.18 (B2)
/JX2_connections/PMOD1 & PMOD2 connections/PMOD1_1P: PMODH1.1 (IO1), PMODV1.1 (IO1), U3.20 (B1)
/JX2_connections/PMOD1 & PMOD2 connections/PMOD1_2N: PMODH1.4 (IO4), PMODV1.4 (IO4), U3.16 (B4)
/JX2_connections/PMOD1 & PMOD2 connections/PMOD1_2P: PMODH1.3 (IO3), PMODV1.3 (IO3), U3.17 (B3)
/JX2_connections/PMOD1 & PMOD2 connections/PMOD1_3N: PMODH1.6 (IO6), PMODV1.6 (IO6), U3.14 (B6)
/JX2_connections/PMOD1 & PMOD2 connections/PMOD1_3P: PMODH1.5 (IO5), PMODV1.5 (IO5), U3.15 (B5)
/JX2_connections/PMOD1 & PMOD2 connections/PMOD1_4N: PMODH1.8 (IO8), PMODV1.8 (IO8), U3.12 (B8)
/JX2_connections/PMOD1 & PMOD2 connections/PMOD1_4P: PMODH1.7 (IO7), PMODV1.7 (IO7), U3.13 (B7)
/JX2_connections/PMOD1 & PMOD2 connections/PMOD2_B1: PMODH2.1 (IO1), PMODV2.1 (IO1), U4.20 (B1)
/JX2_connections/PMOD1 & PMOD2 connections/PMOD2_B2: PMODH2.2 (IO2), PMODV2.2 (IO2), U4.18 (B2)
/JX2_connections/PMOD1 & PMOD2 connections/PMOD2_B3: PMODH2.3 (IO3), PMODV2.3 (IO3), U4.17 (B3)
/JX2_connections/PMOD1 & PMOD2 connections/PMOD2_B4: PMODH2.4 (IO4), PMODV2.4 (IO4), U4.16 (B4)
/JX2_connections/PMOD1 & PMOD2 connections/PMOD2_B5: PMODH2.5 (IO5), PMODV2.5 (IO5), U4.15 (B5)
/JX2_connections/PMOD1 & PMOD2 connections/PMOD2_B6: PMODH2.6 (IO6), PMODV2.6 (IO6), U4.14 (B6)
/JX2_connections/PMOD1 & PMOD2 connections/PMOD2_B7: PMODH2.7 (IO7), PMODV2.7 (IO7), U4.13 (B7)
/JX2_connections/PMOD1 & PMOD2 connections/PMOD2_B8: PMODH2.8 (IO8), PMODV2.8 (IO8), U4.12 (B8)
/JX2_connections/SWITCH1: C9.1, JX2.19 (IO_L1N_T0_AD0N), R19.1, R20.1
/JX2_connections/SWITCH2: C13.1, JX2.13 (IO_0), R22.1, R27.1
/VADJ_EN: R12.2, R23.1, REG1.1 (EN), TP8.1, U1.4
GND: C1.2, C2.2, C3.2, C4.2, C5.1, C6.2, C7.2, C8.2, C9.2, C10.2, C11.1, C12.2, C13.2, C14.2, C15.1, C16.2, C17.2, C18.2, C19.1, C20.2, C21.2, C22.2, CON1.5 (GND), CON1.6 (Shield), CON1.7 (Shield), CON1.8 (Shield), CON1.9 (Shield), CON2.5 (GND), CON2.6 (Shield), CON2.7 (Shield), CON2.8 (Shield), CON2.9 (Shield), J1.2, J2.1, J2.2, J2.3, J2.4, J5.3, J5.4, J5.5, J5.6, J6.3, J6.4, J6.5, J6.6, J7.1, J7.2, J7.3, J7.4, JP2.3 (B), JX1.15 (GND), JX1.16 (GND), JX1.21 (GND), JX1.22 (GND), JX1.27 (GND), JX1.28 (GND), JX1.33 (GND), JX1.34 (GND), JX1.39 (GND), JX1.40 (GND), JX1.45 (GND), JX1.46 (GND), JX1.51 (GND), JX1.52 (GND), JX1.65 (GND), JX1.66 (GND), JX1.71 (GND), JX1.72 (GND), JX1.77 (GND), JX1.85 (GND), JX1.86 (GND), JX1.95 (GND), JX1.96 (GND), JX2.15 (GND), JX2.16 (GND), JX2.21 (GND), JX2.22 (GND), JX2.27 (GND), JX2.28 (GND), JX2.33 (GND), JX2.34 (GND), JX2.39 (GND), JX2.40 (GND), JX2.45 (GND), JX2.46 (GND), JX2.51 (GND), JX2.52 (GND), JX2.65 (GND), JX2.66 (GND), JX2.71 (GND), JX2.72 (GND), JX2.77 (GND), JX2.85 (GND), JX2.86 (GND), JX2.91 (GND), JX2.92 (GND), PMODH1.9 (GND), PMODH2.9 (GND), PMODH3.9 (GND), PMODV1.9 (GND), PMODV2.9 (GND), PMODV3.9 (GND), Q2.2 (S), Q3.2 (S), Q4.2 (S), R4.2, R7.2, R8.1, R14.2, R16.2, R20.2, R23.2, R25.2, R26.2, R27.2, REG1.2 (GND), REG1.3 (MODE), REG1.9 (pad), TP2.1, TP14.1, TP16.1, U1.2 (V-), U2.3 (A), U3.11 (GND), U4.11 (GND), U5.1 (GND), U6.3 (GND), X1.2 (GND), Y1.2, Y1.4
unnamed: D1.2 (A), R17.2
unnamed: D1.1 (K), Q3.3 (D)
unnamed: D2.2 (A), R18.2
unnamed: D2.1 (K), Q4.3 (D)
unnamed: D3.1 (K), R25.1
unnamed: D4.1 (K), R26.1
unnamed: D5.1, R11.1
unnamed: D6.2 (A), R15.2
unnamed: D7.2 (A), R24.2
unnamed: D7.1 (K), U6.4 (Y)
unnamed: JP1.1 (A), R5.1
unnamed: D8.3, JP1.2 (B), R7.1, U1.3 (+)
unnamed: JP2.2 (C), R1.1, R2.1
unnamed: JX1.8 (DONE), TP12.1
unnamed: JX1.7 (VCCBATT), TP11.1
unnamed: C16.1, Q2.1 (G), R6.1, R8.2
unnamed: L1.1, REG1.7 (SW)
unnamed: R19.2, SW1.3 (K), SW1.4 (A)
unnamed: R22.2, SW2.3 (K), SW2.4 (A)
unnamed: R10.2, R16.1, U1.1 (-)
unnamed: C21.1, U5.7 (XI), Y1.3
unnamed: C22.1, U5.8 (XO), Y1.1
unnamed: R3.2, R4.1, X1.1 (Vctrl)
PG_CARRIER: JX2.11 (PG_CARRIER), R13.1, REG1.6 (PG), TP10.1
PWR_EN: D5.3, JX1.5 (PWR_EN), Q2.3 (D), R14.1, TP5.1
VCCIO: C4.1, C5.2, C6.1, C10.1, C11.2, C12.1, C18.1, C19.2, D4.2 (A), J5.7, J5.8, J6.7, J6.8, JX1.78 (VCCIO_34), JX1.79 (VCCIO_34), JX1.80 (VCCIO_34), JX2.78 (VCCIO_35), JX2.79 (VCCIO_35), JX2.80 (VCCIO_35), JX2.98 (VCCO_13), L1.2, PMODH3.10 (VCC), PMODV3.10 (VCC), R1.2, R13.2, R15.1, R17.1, R18.1, R24.1, REG1.5 (VOS), SW1.1, SW1.2, SW2.1, SW2.2, TP9.1, U3.2 (VCCA), U3.10 (OE), U4.2 (VCCA), U4.10 (OE), U5.4 (V3), U5.16 (VCC), U6.6 (VCC), X1.4 (V+)
VCCIO_EN: D8.1, JX2.10 (VCCIO_EN), TP7.1
VIN: C17.1, CON1.1 (VBUS), J1.1, R9.2, SW3.2 (B), TP1.1, U1.5 (V+)

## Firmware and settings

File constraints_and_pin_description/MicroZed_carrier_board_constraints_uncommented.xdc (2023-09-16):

## This file is a general .xdc for the MicroZed development carrier board, Rev. 4
## https://github.com/viktor-nikolov/MicroZed-carrier-board
##
## To use it in a project:
## - uncomment the lines corresponding to used pins
## - rename the used ports (in each line, after get_ports) according to the top level signal names in the project

############  LEDs and switches  ############
set_property -dict { PACKAGE_PIN C20 IOSTANDARD LVCMOS33 } [get_ports { LED1    }];
set_property -dict { PACKAGE_PIN J15 IOSTANDARD LVCMOS33 } [get_ports { LED2    }];
set_property -dict { PACKAGE_PIN B20 IOSTANDARD LVCMOS33 } [get_ports { SWITCH1 }];
set_property -dict { PACKAGE_PIN G14 IOSTANDARD LVCMOS33 } [get_ports { SWITCH2 }];

############  50 MHz oscillator input  ############
set_property -dict { PACKAGE_PIN N18 IOSTANDARD LVCMOS33 } [get_ports { OSC_50MHZ }];

############  PMOD1  ############
## Beware that output of PMOD1 is shifted to 5V!
set_property -dict { PACKAGE_PIN G19 IOSTANDARD LVCMOS33 } [get_ports { PMOD1_1 }];
set_property -dict { PACKAGE_PIN G20 IOSTANDARD LVCMOS33 } [get_ports { PMOD1_2 }];
set_property -dict { PACKAGE_PIN K14 IOSTANDARD LVCMOS33 } [get_ports { PMOD1_3 }];
set_property -dict { PACKAGE_PIN J14 IOSTANDARD LVCMOS33 } [get_ports { PMOD1_4 }];
set_property -dict { PACKAGE_PIN N15 IOSTANDARD LVCMOS33 } [get_ports { PMOD1_5 }];
set_property -dict { PACKAGE_PIN N16 IOSTANDARD LVCMOS33 } [get_ports { PMOD1_6 }];
set_property -dict { PACKAGE_PIN M14 IOSTANDARD LVCMOS33 } [get_ports { PMOD1_7 }];
set_property -dict { PACKAGE_PIN M15 IOSTANDARD LVCMOS33 } [get_ports { PMOD1_8 }];

############  PMOD2  ############
## Beware that output of PMOD2 is shifted to 5V!
set_property -dict { PACKAGE_PIN M17 IOSTANDARD LVCMOS33 } [get_ports { PMOD2_1 }];
set_property -dict { PACKAGE_PIN M18 IOSTANDARD LVCMOS33 } [get_ports { PMOD2_2 }];
set_property -dict { PACKAGE_PIN L16 IOSTANDARD LVCMOS33 } [get_ports { PMOD2_3 }];
set_property -dict { PACKAGE_PIN L17 IOSTANDARD LVCMOS33 } [get_ports { PMOD2_4 }];
set_property -dict { PACKAGE_PIN H16 IOSTANDARD LVCMOS33 } [get_ports { PMOD2_5 }];
set_property -dict { PACKAGE_PIN H17 IOSTANDARD LVCMOS33 } [get_ports { PMOD2_6 }];
set_property -dict { PACKAGE_PIN G17 IOSTANDARD LVCMOS33 } [get_ports { PMOD2_7 }];
set_property -dict { PACKAGE_PIN G18 IOSTANDARD LVCMOS33 } [get_ports { PMOD2_8 }];

############  PMOD3  ############
set_property -dict { PACKAGE_PIN P16 IOSTANDARD LVCMOS33 } [get_ports { PMOD3_1 }];
set_property -dict { PACKAGE_PIN P15 IOSTANDARD LVCMOS33 } [get_ports { PMOD3_2 }];
set_property -dict { PACKAGE_PIN W19 IOSTANDARD LVCMOS33 } [get_ports { PMOD3_3 }];
set_property -dict { PACKAGE_PIN W18 IOSTANDARD LVCMOS33 } [get_ports { PMOD3_4 }];
set_property -dict { PACKAGE_PIN R18 IOSTANDARD LVCMOS33 } [get_ports { PMOD3_5 }];
set_property -dict { PACKAGE_PIN T17 IOSTANDARD LVCMOS33 } [get_ports { PMOD3_6 }];
set_property -dict { PACKAGE_PIN W16 IOSTANDARD LVCMOS33 } [get_ports { PMOD3_7 }];
set_property -dict { PACKAGE_PIN V16 IOSTANDARD LVCMOS33 } [get_ports { PMOD3_8 }];
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

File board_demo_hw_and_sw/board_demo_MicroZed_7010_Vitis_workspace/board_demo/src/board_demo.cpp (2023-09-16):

/*****************************************************************************************
This is the demo program for the MicroZed development carrier board
(https://github.com/viktor-nikolov/MicroZed-carrier-board).

It assumes the HW specification as exported to board_demo/board_demo_MicroZed_7010_hw/system_wrapper.xsa

The demo does the following:

- Board's LED1 and LED2 blink with 2.5 Hz frequency.

- Board's SWITCH1 disables blinking of LED1. SWITCH2 disables LED2.

- Testing serial output is provided on the UART Micro-USB connector.
  - Connect your computer to the board's UART Micro-USB connector. A new COM port should became
    available in the operating system. Connect a terminal program (e.g. PuTTY) to given COM port,
    set the speed to 9600 baud. You then shall see increasing series of numbers in the terminal (25 lines per second).
  - Activity of the board's serial output is also indicated by fast blinking yellow TX LED on the board.

- J3_1 provides the 3.3 V square wave signal of frequency 5 kHz, which is exactly ten thousand times
  de-scaled 50 MHz frequency signal from the oscillator X1.

- Other pins with odd pin number on J3, J4 and PMODs provide the square wave signal
  of frequency 166.6 Hz (5 V on PMOD1 and PMOD2, 3.3 V on other connectors).

- Pins with even pin number on J3, J4 and PMODs provide the square wave signal of frequency 80.6 Hz.

Following pins are NOT USED by the demo:
- J3_32_UART_RX   - serial receive pin from the USB-to-UART chip.
- J3_46 and J3_47 - analog input ports XADC VP/VN.
- J3_50 and J3_51 - temperature-sensing diode pins not usable by PL (see 7 Series Pinout UG475, Table1-12).

- Following pins DO NOTHING when using MicroZed 7010, because respective Zynq pins simply don't
  exist on the 7010 chip:
  - J3_26
  - J3_42..45
  - J3_48..49
  - J3_52
  - J4_18..19
  - J4_34..38

 -------------------------------------------------------------------------------
 | UART TYPE                      BAUD RATE                                    |
 -------------------------------------------------------------------------------
   ps7_uart                        115200 (configured by bootrom/bsp)
   UART on Micro-USB on the board    9600 (configured on the AXI UART Lite IP)


BSD 2-Clause License

Copyright (c) 2023, Viktor Nikolov

Redistribution and use in source and binary forms, with or without
modification, are permitted provided that the following conditions are met:
1. Redistributions of source code must retain the above copyright notice, this
   list of conditions and the following disclaimer.
2. Redistributions in binary form must reproduce the above copyright notice,
   this list of conditions and the following disclaimer in the documentation
   and/or other materials provided with the distribution.
THIS SOFTWARE IS PROVIDED BY THE COPYRIGHT HOLDERS AND CONTRIBUTORS "AS IS"
AND ANY EXPRESS OR IMPLIED WARRANTIES, INCLUDING, BUT NOT LIMITED TO, THE
IMPLIED WARRANTIES OF MERCHANTABILITY AND FITNESS FOR A PARTICULAR PURPOSE ARE
DISCLAIMED. IN NO EVENT SHALL THE COPYRIGHT HOLDER OR CONTRIBUTORS BE LIABLE
FOR ANY DIRECT, INDIRECT, INCIDENTAL, SPECIAL, EXEMPLARY, OR CONSEQUENTIAL
DAMAGES (INCLUDING, BUT NOT LIMITED TO, PROCUREMENT OF SUBSTITUTE GOODS OR
SERVICES; LOSS OF USE, DATA, OR PROFITS; OR BUSINESS INTERRUPTION) HOWEVER
CAUSED AND ON ANY THEORY OF LIABILITY, WHETHER IN CONTRACT, STRICT LIABILITY,
OR TORT (INCLUDING NEGLIGENCE OR OTHERWISE) ARISING IN ANY WAY OUT OF THE USE
OF THIS SOFTWARE, EVEN IF ADVISED OF THE POSSIBILITY OF SUCH DAMAGE.
******************************************************************************************/

#include <vector>
#include "xil_printf.h"
#include "xgpiops.h"
#include "sleep.h"

#define PS_LED_PIN   47  //MIO pin 47 = PS LED on MicroZed

#define PL_LED_PIN   54  //= EMIO pin 0, connected to LEDs on the carrier board
#define PL_EVEN_PIN  55  //= EMIO pin 1, connected to even pins on the carrier board
#define PL_ODD_PIN   56  //= EMIO pin 2, connected to odd pins on the carrier board

XGpioPs GpioInstance;

int initialiseGPIO()
{
	XGpioPs_Config *GpioConfig;

	GpioConfig = XGpioPs_LookupConfig(XPAR_PS7_GPIO_0_DEVICE_ID);
	if(GpioConfig == NULL) {
		print("XGpioPs_LookupConfig failed\r\n");
		return XST_FAILURE;
	}

	int Status = XGpioPs_CfgInitialize(&GpioInstance, GpioConfig, GpioConfig->BaseAddr);
	if(Status != XST_SUCCESS) {
		print("XGpioPs_CfgInitialize failed\r\n");
		return XST_FAILURE;
	}

  //configure output pins
	const std::vector<int> outputPins = { PS_LED_PIN, PL_LED_PIN, PL_EVEN_PIN, PL_ODD_PIN  };
	for( auto p : outputPins ) {
		XGpioPs_SetDirectionPin(&GpioInstance, p, 1 /*output*/);
		XGpioPs_SetOutputEnablePin(&GpioInstance, p, 1 /*enable*/);
	}

    return XST_SUCCESS;
}


int main()
{
    print("***** MicroZed carrier board demo started *****\n\r");

    if( initialiseGPIO() != XST_SUCCESS )
    	return XST_FAILURE;

    const unsigned SLEEP_INTERVAL{100},
                   LED_TICKS{1999},     //  2.5 Hz
                   EVEN_PIN_TICKS{61},  // 80.6 Hz
                   ODD_PIN_TICKS{29};   //166.6 Hz
    unsigned LEDTickCounter{0}, EvenPinTickCounter{0}, OddPinTickCounter{0};
    unsigned LEDState{0}, EvenPinState{0}, OddPinState{0};

    while(1) {
        if( LEDTickCounter == LED_TICKS ) {
        	LEDTickCounter = 0;
        	LEDState = !LEDState;
        	XGpioPs_WritePin( &GpioInstance, PS_LED_PIN, LEDState );
        	XGpioPs_WritePin( &GpioInstance, PL_LED_PIN, LEDState );
        }
        else
        	LEDTickCounter++;

        if( EvenPinTickCounter == EVEN_PIN_TICKS ) {
        	EvenPinTickCounter = 0;
        	EvenPinState = !EvenPinState;
        	XGpioPs_WritePin( &GpioInstance, PL_EVEN_PIN, EvenPinState );
        }
        else
        	EvenPinTickCounter++;

        if( OddPinTickCounter == ODD_PIN_TICKS ) {
        	OddPinTickCounter = 0;
        	OddPinState = !OddPinState;
        	XGpioPs_WritePin( &GpioInstance, PL_ODD_PIN, OddPinState );
        }
        else
        	OddPinTickCounter++;

    	usleep( SLEEP_INTERVAL );
    }

    return 0; //never reaches to here
}

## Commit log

2023-09-22 Update list of parts
    [MicroZed_carrier_board_v4_parts.xlsx]
2023-09-24 Remove folder
    [bom.csv, positions.csv]
2023-09-24 Components rotation offsets added
    [JX2_connections.kicad_sch, MicroZed_carrier_board_v4.kicad_pcb, MicroZed_carrier_board_v4.kicad_sch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]
2023-09-24 Update of license to CC0
    [JX1_connections.kicad_sch, JX2_connections.kicad_sch, MicroZed_carrier_board_v4.kicad_pcb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]

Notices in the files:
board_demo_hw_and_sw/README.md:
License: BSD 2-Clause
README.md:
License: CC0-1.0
